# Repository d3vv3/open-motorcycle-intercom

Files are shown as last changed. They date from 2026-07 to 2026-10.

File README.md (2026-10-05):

<p align="center">
    OpenHelmet Logo
    <br/>
    <b>Open Source Mesh and Bluetooth Motorcycle Intercom</b>
    <br/>
    <br/>
    <a href="https://openhelmet.devve.space">website</a> | <a href="https://discord.gg/XxBSnwSDst">discord</a>
</p>

OpenHelmet is an **open-source, motorcycle intercom system**
designed to outperform current proprietary solutions in **latency, scalability, transparency, and hackability**.

## Key goals

- Open protocol and open firmware
- Commodity, off-the-shelf hardware
- Use any microphone and any speakers from your existing helmet setup
- Mesh networking for 4-8+ riders
- Real-time full-duplex voice
- 8-16 hours of active riding per charge
- Bluetooth phone and media audio (calls, GPS, music, etc)
- Interoperability with legacy Bluetooth intercoms (Cardo, Sena, etc.) via standard profiles

This project explicitly avoids reverse-engineering proprietary intercom protocols.
Interoperability is achieved **only through standard Bluetooth audio profiles**.

---

## Why

- Cardo/Sena mesh protocols are proprietary and closed
- True mesh interoperability with and between them is impossible today
- Voice communication requires **deterministic latency**, not best-effort networking

As a result, OpenHelmet is designed around **custom real-time audio transport**.

---

## Roadmap

### Single-MCU

See [the wiring guide](docs/wiring.md) for the ESP32-S31 Function CoreBoard-1.

- [x] **ESP32-S31 Function CoreBoard-1** with 16 MB flash and 16 MB PSRAM
- [x] Onboard ES8311 capture/codec and NS4150B/J9 output
- [x] TDMA mesh protocol over [ESP-NOW](https://www.espressif.com/en/solutions/low-power-solutions/esp-now) (2.4 GHz)
- [x] LC3 low-bitrate voice
- [x] Classic Bluetooth A2DP sink, AVRCP, and HFP HF client
- [x] VOX for voice activation
- [x] Configure ESP32 tx power to 20 dBm (100 mW) for ESP-NOW
- [x] Silence suppression - most silent audio frames are suppressed; control traffic and occasional comfort updates remain
- [x] Receive mixing with first-speaker retention; a new active source can replace the longest-silent source after 400 ms

Limitations:
- ESP-NOW is not interoperable with nRF52 ESB.
- The ESP-NOW and Bluetooth stacks share the same radio, so mesh cannot reach realtime performance when Bluetooth is active.

### Dual-MCU

Development and validation only. Check [the wiring guide](docs/wiring.md) for
the S31/nRF52840 SPI wiring.

The nRF52840 firmware uses the radio's +8 dBm output directly.
An nRF21540 is needed for additional range, efficiency and antenna radio distribution. See "Custom PCB" section below.

> The nRF21540 is needed for actual range improvements.
> The nRF52840 alone is not a range improvement over the ESP32-S31.

- [x] **ESP32-S31 + Nordic nRF52840**
- [x] TDMA mesh protocol over [ESB](https://docs.nordicsemi.com/bundle/ncs-latest/page/nrf/protocols/esb/index.html) radio with custom PHY control
  > ESB is configured for 2 Mbps with +8 dBm TX power (`OMI_ESB_BITRATE` / `OMI_ESB_TX_POWER_DBM`).
- [x] SPI audio & control bridge between MCUs
  > The nRF52840 is the SPI master and polls the ESP32 bridge every 2 ms.
- [x] Noise suppression and echo cancellation paths
- [ ] Allow user to choose between [ESP-NOW](https://www.espressif.com/en/solutions/low-power-solutions/esp-now) and [ESB](https://docs.nordicsemi.com/bundle/ncs-latest/page/nrf/protocols/esb/index.html)
  > ESP-NOW is not interoperable with nRF52 ESB. The firmware currently selects ESB when the bridge is detected and otherwise falls back to ESP-NOW; comparative range, power, and latency remain to be measured.
- [x] Relay grants limited to at most two active speakers
- [x] Three-source receive mixer with first-speaker retention and 400 ms silent-source eviction
- [x] Silence suppression - most silent audio frames are suppressed; control traffic and occasional comfort updates remain
- [x] Bluetooth media playback (music, GPS, etc.) during mesh operation.

### Custom PCB

- [x] Schematic
- [ ] PCB layout
- [x] Include [nRF21540 RF FEM](https://www.nordicsemi.com/Products/nRF21540) in the schematics and PCB design

See the [wiring guide](docs/wiring.md) for the current assembled prototype.

### Ongoing

- [x] Mute mesh during phone call; resume mesh after call ends
- [x] Mesh channels with RGB LED channel indicator by color (e.g. green=1, red=2, blue=3, etc.)
- [x] Buttons for channel selection, volume, mesh toggle, and Bluetooth pairing
- [x] Multi-hop mesh
- [x] Replace beeps with voice prompts for button operations
- [ ] Power budgeting and optimization for 8-16 hours of active riding per charge
- [ ] Testing on real motorcycle rides
- [ ] E2EE

---

## Transport Protocol Design

### Why Not Bluetooth Mesh / BLE Audio

- High latency
- Unpredictable scheduling
- Poor scaling for continuous audio

These technologies are unsuitable for real-time group voice.

---

## Custom Mesh Strategy

### Scheduled Voice and Control

OpenHelmet divides each 20 ms TDMA frame into scheduled voice slots and a control window:

- **TDMA** for mesh audio packets
- A rotating owner for joined-node control traffic; coordinator SYNC frames have a reserved window
- Bounded randomized contention for unjoined ESP-NOW JOIN requests

#### TDMA (Voice)

Each current mesh audio payload represents 20 ms of sound: two 10 ms LC3 frames, encoded as 24 bytes each. These 48 bytes travel together in one packet, not in separate TDMA slots.

On the nRF transport, a bundle can also carry previous audio frames for loss recovery. This increases packet size without changing the 20 ms transmission cadence.

- Fixed time slots per node
- One bounded transmission opportunity per node per 20 ms TDMA frame
- Deadline checks reject work that is already late; they do not guarantee exact RF completion timing

Configured frame structure (20 ms frame, up to 8 nodes; durations include guard time):

```
| Slot 1 | Slot 2 | Slot 3 | ... | Slot 8 | Control | Margin |
|  2 ms  |  2 ms  |  2 ms  | ... |  2 ms  |   2 ms  |  2 ms |
```

- Voice slots: 8 × 2 ms = 16 ms
- Control window: 2 ms (scheduled sync/topology/status traffic)
- Frame margin: 2 ms
- Voice and control deadlines reserve the last 500 µs of each nominal 2 ms window, leaving 1.5 ms before the deadline

VOX suppresses local LC3 encoding and audio transmission during silence, after its hangover period. Capture and voice detection continue. The TDMA schedule remains unchanged, and synchronization, keepalives, and required relay/control traffic continue.

Motorcycle groups are small and topology changes slowly, making TDMA practical.

#### Control

Used for:
- Joining/leaving the group
- Topology updates
- Slot maps and synchronization

Joined-node control packets use a bounded queue and scheduled ownership. Unassigned ESP-NOW JOIN requests use a minimum interval plus randomized jitter. These rules reduce contention, but they do not guarantee collision-free RF operation.

---

## Quick Start

For published paired flash bundles and the alpha/stable release process, see
[Firmware releases](docs/releases.md).

### Prerequisites

- [ESP-IDF v6.1 preview](https://docs.espressif.com/projects/esp-idf/en/release-v6.1/esp32s31/get-started/)
- [ESP32-S31 Function CoreBoard-1](https://docs.espressif.com/projects/esp-idf/en/release-v6.1/esp32s31/get-started/) with 16 MB flash and 16 MB PSRAM
- ESP32-S31 support in ESP-IDF v6.1 is preview
- CI pins a tested ESP-IDF image that includes the upstream S31 Bluetooth
  sniff-subrate fix. The mutable `v6.1` tag does not contain that fix.
- (Optional) XIAO nRF52840
- USB-C data cables
- [Development environment and ESP32 setup](docs/getting_started.md)
- [Audio and dual-MCU wiring guide](docs/wiring.md)
- (Optional) [KiCad](https://www.kicad.org/)

### Build

```bash
# Optional local environment example (path is machine-specific; this installation
# may use the unpatched v6.1 image and does not include the S31 sniff-subrate fix)
source "$HOME/.espressif/tools/activate_idf_v6.1.sh"

# Select the ESP32-S31 preview target
idf.py --preview set-target esp32s31

# Build firmware
idf.py build
```

For the tested SDK image with the tested fix, use the same immutable image as CI
instead of a local v6.1 installation:

```bash
docker run --rm --user "$(id -u):$(id -g)" -e HOME=/tmp \
  -v "$PWD:/project" -w /project \
  espressif/idf@sha256:8ac794c57fd4cac246cb8d2ada4002fa26337ac7df683047b5b83743dbedb6b7 \
  bash -lc 'idf.py --preview set-target esp32s31 && idf.py build'
```

That image reports ESP-IDF commit `9a97f6c54ec638111ce55cd36581b3c192f15207`
and S31 Bluetooth binary commit `3d8cee57c4ccff603d4f52fe16be1f04ece78ede`;
the latter includes the upstream sniff-subrate fix. The stable `espressif/idf:v6.1`
tag does not include this fix. A delayed BOOT guard alone does not fix
phone-originated transitions: cooldown handling and the external Bluetooth
controller fix are also required.

For the optional XIAO nRF52840 firmware, use nRF Connect SDK v3.4.1 and the same board target as CI:

```bash
west build -b xiao_ble/nrf52840 ./nrf_mesh -d ./build-nrf
```

### Recovery and Flashing

```bash
# Find your serial port
ls /dev/ttyACM* /dev/ttyUSB*

# Native USB JTAG/OpenOCD with board/esp32s31-builtin.cfg is the validated
# recovery path on the current setup. Serial flashing has proved unreliable here.
```

### Monitor Serial Output

```bash
# Option 1: Using idf.py (interactive, requires TTY)
idf.py -p /dev/ttyACM0 monitor

# Option 2: Using stty + cat (non-interactive)
stty -F /dev/ttyACM0 115200 raw -echo && cat /dev/ttyACM0
```

**Exit monitor:** `Ctrl+]`

### Expected Boot Log

```
I (xxx) omi: ========================================
I (xxx) omi: OMI - Open Motorcycle Intercom
I (xxx) omi: Phase 2: Single-Hop RF Link
I (xxx) omi: ========================================
I (xxx) omi: Boot time: <milliseconds> ms
I (xxx) omi: IDF version: v6.1
I (xxx) omi: Free heap: <bytes> bytes
I (xxx) omi: ========================================
I (xxx) omi: nRF52840 not detected - using ESP-NOW transport
I (xxx) omi: Mesh networking ready (desired state: disabled)
I (xxx) omi: System running!
```

### Troubleshooting

| Issue | Solution |
|---|---|
| Device not found | Use a data cable (not charge-only), try different USB port |
| Garbage characters in monitor | Wrong baud rate, use 115200 |

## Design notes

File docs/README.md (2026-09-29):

# OpenHelmet Documentation

See the [project README](../README.md) for an overview and project progress.

## Start Here

- [Getting started](getting_started.md): development setup, firmware builds, and initial checks.
- [Wiring](wiring.md): CoreBoard audio, XIAO SPI connections, power arrangements, and flashing preparation.
- [Button controls](buttons.md): three external buttons and voice prompts; BOOT is for ROM download only on new S31 firmware.

## System Design

- [Architecture](architecture.md): component responsibilities and transport selection.
- [Audio pipeline](audio.md): capture, codecs, playback, and Bluetooth audio routes.
- [Mesh protocol](protocol.md): packet formats, mesh control messages, and SPI flow control.
- [Adaptive mesh](mesh.md): topology, relay and handover contracts, limits, and hardware verification plan.
- [TDMA scheduling](tdma.md): voice slots, control windows, and timing constraints.

## Testing and Development

- [Pipeline telemetry](pipeline_telemetry.md): counters and tools for tracing audio delivery and drops.
- [CPU profiling](s31-cpu-profiling.md): optional task profiling, timing measurements, and interpretation limits.

## Investigation History

- [S31 Bluetooth / ESP-NOW coexistence](s31-bluetooth-coexistence.md): September 2026 experiments using the S31's shared radio.
  This report predates the separate nRF ESB setup and does not describe its performance.

The documentation is being updated for LC3, protocol v5, and NCS 3.4.1.
Some linked guides still describe earlier versions; dated reports retain their original test context.

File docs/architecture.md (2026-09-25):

# Architecture Overview

OpenHelmet uses an ESP32-S31 Function CoreBoard-1 for audio and phone connectivity.
An optional XIAO nRF52840 Sense provides a separate mesh radio.

## System Map

```mermaid
flowchart LR
    Phone[Phone] <-->|Bluetooth| S31[ESP32-S31]
    Mic[Onboard microphone] --> S31
    S31 --> Speaker[Speaker]
    S31 <-->|SPI: encoded LC3 audio and control| NRF[nRF52840]
    NRF <-->|ESB| Peers[Other mesh nodes]
```

The diagram shows the separate-radio setup. The nRF forwards encoded audio; it does not run the audio codec.

| Responsibility | Owner |
|---|---|
| Microphone capture, VOX, LC3 encoding and decoding | S31 |
| Playback, music mixing, and notification sounds | S31 |
| Bluetooth music, media controls, and phone-call routes | S31 |
| Buttons and application policy | S31 |
| ESB radio, mesh membership, TDMA, and relaying | nRF, when selected |
| SPI transfers | nRF master, S31 slave |

Mesh audio is 16 kHz mono. Each 20 ms audio payload contains two 10 ms LC3 frames.
VOX silence stops local encoding and audio transmission, while capture and mesh control traffic continue.

## Transport Selection

At startup, the S31 probes for a compatible LC3 nRF bridge.

- **nRF ESB:** The nRF owns mesh communication. S31 Wi-Fi and ESP-NOW are disabled; Bluetooth remains enabled.
- **ESP-NOW fallback:** Without a compatible bridge, the S31 also owns the mesh radio and TDMA schedule.

Mesh voice, Bluetooth music, and notifications can mix locally. Phone calls take priority over those playback sources.

Bluetooth music and two-way mesh voice have worked together on two nRF-equipped pairs.
Larger groups and sustained call performance still need validation.

## Details

- [Wiring and power](wiring.md)
- [Audio pipeline](audio.md)
- [Packet formats and SPI flow control](protocol.md)
- [TDMA scheduling](tdma.md)
- [Button gestures](buttons.md)

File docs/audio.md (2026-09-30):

# Audio Pipeline

This page describes the tested ESP32-S31 LC3 mesh configuration. The S31 handles all audio processing;
the nRF52840 transports encoded audio over ESB.

## Formats and Signal Path

| Domain | Format | Samples per 20 ms |
|---|---|---:|
| Hardware capture and playback | 48 kHz, mono, signed 16-bit PCM | 960 |
| Mesh voice | 16 kHz, mono, signed 16-bit PCM | 320 |
| Encoded mesh audio | Two 10 ms LC3 frames, 24 bytes each | 48 bytes total |

The LC3 payload rate is 19.2 kbit/s, excluding headers and redundancy.

```text
Microphone -> 48-to-16 kHz conversion -> voice cleanup -> VOX -> LC3 -> mesh
Mesh -> packet recovery -> LC3 decode -> voice mix -> 16-to-48 kHz conversion -> speaker
Bluetooth music -> stereo downmix and rate conversion -> speaker mix
```

The onboard ES8311 codec and NS4150B amplifier handle physical audio I/O.
See [wiring](wiring.md) for the speaker connection and pin details.

## Codec Ownership and Memory

The tested build enables `ESP_LC3_BENCH`, `S31_LC3_WIRE`, `S31_LC3_SERIALIZE`, and `S31_LC3_SINGLE_OWNER`.
These CMake options default to OFF; the benchmark and serialization options are prerequisites for this path.
Capture, playout, and the dedicated LC3 owner task run on core 1.
All vendor LC3 operations run through the owner task, including resets. Preserve this arrangement when changing task placement.

Mesh mode uses LC3; local codec loopback still uses Opus.
The nRF does not encode, decode, or mix audio.

Audio initialization requires the CoreBoard's expected 16 MB PSRAM.
Route buffers and Speex resampler state and scratch buffers use PSRAM in the S31 configuration.
Speex uses fixed-point quality-3 resampling, with a full sinc table to reduce conversion work.

## VOX and Silence

VOX measures microphone RMS once per 20 ms frame. Current defaults are:

- Activation threshold: `0.03` of full scale; deactivation threshold: `0.010`.
- Minimum active time: 500 ms; hangover: 500 ms.
- Forced continuous transmission: disabled.

During VOX silence, the LC3 mesh path skips encoding and local audio transmission.
Microphone capture, voice detection, Bluetooth microphone routing, and mesh control traffic continue.
Local silence does not stop reception of other speakers.

There is no pre-roll buffer. Quiet speech before activation can lose its opening milliseconds;
that behavior is currently accepted. RMS detection can also respond to noise or music.

See [protocol.md](protocol.md#lc3-audio-bundles) for quiet-slot sequencing and predecessor handling.

## Receive and Playback

Up to three remote sources have independent packet, decoder, and resampler state.
Predecessor frames can recover missing audio; remaining gaps use concealment before an empty stream becomes idle.
These decoder slots are separate from the mesh's two active-speaker relay grants.

Packet and PCM buffers provide startup prefill and absorb timing variation.
Their presence means codec frame duration alone does not describe end-to-end latency.

Outside phone calls, remote voice, Bluetooth music, and notification tones can mix locally.
An answered or held HFP call gates local mesh mic TX and local mesh playback immediately;
the mesh stays joined and continues control traffic and relaying other participants' audio.
Ringing and outgoing dialing/alerting alone do not gate mesh audio.
An incoming announcement is urgent and canceled on answer, reject, or disconnect;
a completed answered call gets one end beep.
On call end the local gate remains closed until transport audio is flushed,
the mesh RX decoder is reset, and the transport confirms resume.
Audio already submitted to RF or I2S hardware before the call edge cannot be retracted.

## Bluetooth and Voice Cleanup

- **A2DP:** The S31 decodes SBC music, downmixes stereo, and resamples to the 48 kHz speaker domain.
  Hardware playback tests used 44.1 kHz stereo input.
- **AVRCP:** Provides media controls and metadata.
- **HFP:** Hands-Free call audio uses CVSD or mSBC, with 8/16 kHz microphone and playback routes.

Microphone processing includes a high-pass filter and mic-only noise cleanup.
ESP-SR acoustic echo cancellation is disabled. Noise cleanup is not acoustic echo cancellation.
The disabled AEC path also skips unnecessary playback-reference conversion.

See [button gestures](buttons.md) for media, call, mesh, and pairing controls.

## Validation and Diagnostics

Bluetooth music and two-way LC3 mesh voice have worked together on two nRF-equipped pairs.
Quiet-state tests confirmed continued capture with zero LC3 encoding or audio handoff.
Larger groups, sustained calls, and broader acoustic conditions still need testing.

Codec initialization includes a reset sequence that restored speaker output after MCU-only resets.
`AUDIO_OUT` diagnostics report submitted PCM levels, write results, and codec/amplifier register state.
Successful writes and nonzero samples do not prove audible output.

See [pipeline telemetry](pipeline_telemetry.md) for delivery and dropout counters,
or [architecture](architecture.md) for the system overview.

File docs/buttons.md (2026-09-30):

# Buttons

Use the **-**, **play**, and **+** buttons. For setup, see [button wiring](wiring.md#external-buttons).
Hold for the time shown, then release to perform the action.

| Action | Controls |
| --- | --- |
| Mesh volume (Bluetooth call volume during an active or held call) | Tap **- / +** |
| Bluetooth volume (music and calls) | Hold **play** and tap **- / +** |
| Play or pause music | Tap **play** |
| Answer or end a call | Tap **play** |
| Previous or next song | While Bluetooth music is playing, hold **- / +** for **1 second** |
| Previous or next mesh channel | Pause Bluetooth music, then hold **- / +** for **1 second** |
| Turn mesh on or off | Hold **play** for **2-5 seconds** |
| Pair a phone | Hold **play** for **6 seconds**, then connect within **2 minutes** |

- Three beeps mean minimum or maximum volume. Volume levels reset when you restart the device.
- Channels cycle **green -> red -> blue**. The LED shows your channel, which is saved across restarts.
- Use the same channel as the people you want to talk to.
- After adjusting Bluetooth volume, releasing **play** does not trigger another action.
- Bluetooth volume also adjusts the paired phone's volume when supported; music and calls keep separate levels, and call volume moves in coarser steps.
- Incoming calls announce once; ringing does not mute the mesh. Answering or holding a call mutes only this device's mesh microphone and local mesh playback. Other mesh participants remain connected and can relay through this device. Ending the call restores local mesh audio after the transport confirms the flush.

The onboard **BOOT** button is for firmware flashing, not everyday controls.

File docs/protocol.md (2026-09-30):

# Mesh v5 and Bridge v6

The current LC3 firmware uses on-air mesh version `0x05` and SPI bridge version `6`.
The name `AUDIO_V2` identifies a packet format; it does not mean protocol version 2.
For routing, topology, membership, speaker grants, and handover behavior, see [adaptive mesh](mesh.md).

## Mesh Radio Header

Every mesh packet starts with this packed 9-byte header:

| Offset | Field | Bytes | Meaning |
|---:|---|---:|---|
| 0 | `version` | 1 | `0x05` |
| 1 | `type` | 1 | Message ID below |
| 2 | `src_id` | 1 | Source node; `0` for an unassigned joining node |
| 3 | `seq` | 1 | Radio packet sequence |
| 4 | `ttl` | 1 | Remaining hop limit |
| 5 | `flags` | 1 | Relay request, relayed, and speaker-granted bits |
| 6 | `talk_channel` | 1 | Logical talk group (1-3); mismatched groups are rejected |
| 7 | `payload_len` | 2 | Payload length, little-endian |

Assigned node IDs are 1-8; the authoritative slot map assigns their TDMA slots (holes need not be renumbered).
Receivers reject mismatched protocol versions and invalid packet lengths.

| ID | Message | Purpose |
|---:|---|---|
| `0x01` | `AUDIO` | ESP-NOW audio; rejected by the current nRF audio path |
| `0x02` / `0x03` | `JOIN` / `JOIN_ACK` | Legacy membership IDs |
| `0x04` | `LEAVE` | Departure |
| `0x05` / `0x06` | `SYNC` / `SLOT_MAP` | Legacy timing / slot-map ID |
| `0x07` / `0x08` | `STATUS` / `KEEPALIVE` | Node status and liveness |
| `0x09` / `0x0A` | `SPEAKER_GRANT` / `SPEAKER_RELEASE` | Speaker-control IDs |
| `0x0B` / `0x0C` | `JOIN_V2` / `JOIN_ACK_V2` | Legacy identity-bearing membership IDs |
| `0x0D` | `AUDIO_V2` | LC3 bundle used by nRF ESB |
| `0x0E` | `TOPOLOGY` | Direct observations, 32-bit report sequence (47-byte payload) |
| `0x0F` / `0x10` | `JOIN_V3` / `JOIN_ACK_V3` | Identity-bearing targeted JOIN/ACK (15 bytes each) |
| `0x11` | `SYNC_V3` | Term, leader identity, joined member count, frame/phase and relay depth (20 bytes) |
| `0x12`-`0x15` | `HANDOVER_PREPARE` / `ACK` / `COMMIT` / `CANCEL` | Planned handover (25-byte proposal or 11-byte ACK) |
| `0x16` | `MEMBERSHIP_V3` | Full authoritative ID/identity/slot map with term and revision (79 bytes) |
| `0x17` | `SPEAKER_REQUEST` | Pre-grant voice activity/release, 13 bytes; one forwarding hop |

These are shared IDs; not every transport uses every message.
The nRF coordinator requires the LC3 capability bit in `JOIN_V3` requests.
ESP-NOW membership does not enforce the same capability check; use matching firmware on all nodes.

## LC3 Audio Bundles

Mesh voice is 16 kHz mono. Each 20 ms audio unit contains two 10 ms LC3 frames, 24 bytes each.
The nRF forwards these encoded bytes; the S31 performs encoding and decoding.

An `AUDIO_V2` payload begins with an 8-byte header:

```text
codec | frame_ms | stream_id | flags | current_seq (2 bytes) | current_len | previous1_len
```

All fields are one byte except `current_seq`, which is **big-endian**.
The codec is `0x02` (LC3), duration is `20`, and every present audio unit must contain exactly 48 bytes.
`stream_id` identifies the source, not a new speech segment. The S31 accepts zero or the matching source node ID.

Audio data follows in this order: oldest predecessor, immediate predecessor, current audio.
The oldest predecessor's length is inferred from the remaining payload size.

| Flag | Meaning |
|---:|---|
| `0x01` | Current audio active |
| `0x02` / `0x04` | Immediate predecessor present / active |
| `0x08` / `0x10` | Oldest predecessor present / active |
| `0x20` | Relayed bundle indicator |

Other flag bits are rejected. The S31 currently attaches at most one predecessor; the format supports two.

| Audio units | Bundle bytes | Bytes with mesh header |
|---|---:|---:|
| Current only | 56 | 65 |
| Current + one predecessor | 104 | 113 |
| Current + two predecessors | 152 | 161 |

The 16-bit audio sequence is separate from the 8-bit radio packet sequence.
During VOX silence, no LC3 audio is encoded or sent. There is no explicit end-of-speech packet.
The sender clears cached predecessors and advances through at most five quiet sequence slots before holding the sequence.
The receiver uses bounded concealment before treating an empty stream as idle.

ESP-NOW uses its separate `AUDIO` payload format. The S31 LC3 build requires LC3 there too; it does not negotiate codecs.

## Control and Delivery

Coordinator SYNC is scheduled every 200 ms. The nRF queues STATUS and KEEPALIVE every second;
ESP-NOW schedules keepalives every 500 ms. Peer timeout is 3 seconds.
These control messages continue during VOX silence.

The coordinator grants relay service to at most two active speakers. `SPEAKER_REQUEST` can travel through one relay before a grant; voice onset may require several control windows before relayed audio is permitted.
Audio starts with TTL 2; the implemented relay path permits one forwarding hop.
See [TDMA scheduling](tdma.md) for slot ownership and deadlines, and [adaptive mesh](mesh.md) for handover, capacity, and latency caveats.

nRF ESB sends with RF acknowledgments disabled. Lost audio is handled through predecessors and receiver concealment, not RF retransmission.
ESP-NOW completion callbacks have separate MAC-layer semantics; they do not prove application delivery.

## S31/nRF SPI Bridge

The nRF is SPI master; the S31 is slave. Transfers are 256 bytes, mode 0, at 4 MHz.
The polling loop has a nominal 2 ms interval, not a guaranteed transaction deadline.
See [wiring](wiring.md) for connections. The `uart_bridge` name is historical; this link uses SPI.

```text
0xAA | LEN | SEQ | TYPE | PAYLOAD... | CRC8 | zero padding...
```

`LEN = payload_length + 2`. CRC8 covers `LEN` through the payload, using polynomial `0x07` and initial value zero.
The 256-byte transfer allows at most 251 payload bytes. SPI sequence numbers are separate from radio and audio sequences.

| ID | Message | Direction |
|---:|---|---|
| `0x01` | Legacy `AUDIO` | Rejected by current nRF firmware |
| `0x02` | `STATUS` | nRF to S31 |
| `0x03` | `MESH_EVENT` | nRF to S31 |
| `0x04` | `CONTROL` | S31 to nRF |
| `0x05` | `LOG` | nRF to S31 |
| `0x06` | `AUDIO_V2` | Both directions |

S31-to-nRF audio carries the bundle directly. nRF-to-S31 audio prefixes the bundle with one source-ID byte.
Receive timestamps are assigned locally; they are not included in this payload.

### Status and Compatibility

The v6 STATUS payload is 10 bytes, in this order:

```text
role | peer_count | node_id | version | mesh_state | slot_index |
coordinator_id | marker | audio_codec | audio_frame_ms
```

Each field is one byte; `slot_index` is signed. The marker is `0xA5`.
Startup selects nRF only after a fresh status advertises version 6, LC3, and 20 ms audio.
Audio transfer additionally requires an ACTIVE mesh and an assigned node ID.
Older 3-byte and 8-byte statuses remain readable but do not establish LC3 compatibility.

### Two Different Acknowledgments

- **Audio admission:** The nRF pulses GPIO ACK for 20 µs after admitting audio to bounded RAM ingress or recognizing its admitted duplicate.
  The S31 retains and repeats unacknowledged SPI audio until ACK or a 50 ms timeout. ACK does not confirm RF delivery.
- **Commands:** MESH_START (`0x01`), MESH_STOP (`0x02`), AUDIO_PAUSE (`0x04`), and AUDIO_RESUME (`0x05`) carry a three-byte payload: command, generation, talk group (all except START ignore the group). PAUSE and RESUME affect only this node's mesh audio origin and local playback; membership, control and third-party relay continue. PAUSE purges local audio at the nRF, while RESUME requires a fresh local flush first.
  A COMMAND_ACK event returns the command, matching generation, and signed result: zero for success, minus one for failure.

### SPI Flow Control

- Both bridge directions send pending control before audio.
- S31 queued outbound audio expires after 120 ms; transfer requires fresh status reporting an ACTIVE mesh and assigned node ID.
- nRF outbound SPI audio drops the oldest entry when full; it has no age expiry.

The nRF owns ESB, mesh membership, TDMA, relay, and synchronization. The S31
owns codec/audio, phone routes, application policy, and SPI slave state.

## Security

CRC detects accidental corruption; it does not authenticate the sender.
On-air authentication, encryption, key management, and secure firmware update are not implemented.

## Source Definitions

- [Mesh header and message IDs](../shared/mesh_protocol_defs.h)
- [LC3 bundle encoder and parser](../shared/audio_bundle.c)
- [Bridge messages and status layout](../shared/bridge_protocol_defs.h)
- [SPI framing and CRC](../shared/bridge_frame.c)

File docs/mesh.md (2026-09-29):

# Mesh

Mesh lets nearby OMI devices talk to each other without a phone or internet connection.

## Get started

1. Hold the center **play** button for **2-5 seconds**, then release to turn mesh on.
2. Choose the same color channel on every device in your group. Green is the default.
3. Speak normally. Voice activation sends speech automatically; there is no push-to-talk button.

Tap **- / +** to adjust mesh volume. See [Buttons](buttons.md) for all controls, including how to turn mesh off.

## Channels

| Channel | Indicator |
| --- | --- |
| Green (default) | Green LED |
| Red | Red LED |
| Blue | Blue LED |

The LED shows the selected channel, which is saved across restarts.
To change channels, **pause Bluetooth music**, then hold **- / +** for **1 second** and release.
While Bluetooth music is playing, the same holds skip songs instead.

## How it works

One device automatically coordinates the group; you do not need to pick it.
The firmware can rearrange the group as links change.

A device between two others can relay their voices: A to B to C is the limit of **two radio hops**, with one relay, not an unlimited chain.
Relaying adds delay. Separate incoming voices play independently rather than waiting for each other.

The design supports up to **eight devices** and **two simultaneous talkers**.
The start of speech may be clipped, and connection changes may interrupt audio.

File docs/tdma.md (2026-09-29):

# TDMA Scheduling

The implemented mesh schedule is shared by ESP-NOW and nRF ESB.

| Item | Value |
|---|---:|
| Maximum nodes | 8 |
| Frame | 20 ms |
| Voice slots | 8 x 2 ms |
| Guard within each voice/control window | 500 µs |
| Control window | 2 ms, from 16 to 18 ms |
| Frame margin | 2 ms, from 18 to 20 ms |
| SYNC | Every 10 frames, about 200 ms |

Each 20 ms audio payload contains two 10 ms LC3 frames: 24 bytes each, 48 bytes total.
They travel together in one packet.
Redundant previous audio increases packet size, not the transmission cadence.

The authoritative slot map assigns each member's slot;
removing a node may leave a hole without renumbering other members,
including through a planned coordinator handover.
ESP-NOW sends at most one local or relay audio packet per node per frame,
alternating under contention.
nRF ESB may attempt a second packet only if guarded remaining airtime suffices;
full-rate local plus relay is not guaranteed.
Relay grants are limited to two active speakers.

The guard leaves 1.5 ms before each slot's deadline.
Deadline checks reject late work but cannot guarantee RF completion timing.

During VOX silence, local LC3 encoding and audio transmission stop after the hangover period.
Capture and voice detection continue. Slots may remain unused, but synchronization, keepalives, and required relay/control traffic continue.

ESP-NOW discovery uses bounded randomized contention.
ESB discovery uses bounded join retries and scan backoff.
These are discovery exceptions, not a general CSMA voice mode.
The schedule does not guarantee collision-free RF operation.

The nRF owns ESB timing when the bridge is active.
Participants synchronize to the coordinator and reacquire SYNC after loss.
Control-window ownership rotates by slot over eight frames (160 ms);
forwarded SYNC uses the relay's current synchronized frame/phase at TX, not its receive timestamp.
A planned successor also sends SYNC in its own control windows after promotion.
S31 GPIO47 provides a physical 48 kHz WS reference, separate from the 16 kHz mono LC3 audio.
The current runtime does not enable WS-based TDMA clock correction.

Earlier two-board operation has been tested; the new adaptive relay/handover paths still await hardware validation, as does eight-node operation.
Timing counters alone do not prove end-to-end audio latency or RF delivery.

See [protocol.md](protocol.md) for packet and bridge formats and [adaptive mesh](mesh.md) for grant acquisition and latency limits.

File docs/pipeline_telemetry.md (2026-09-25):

# Audio Pipeline Telemetry

Firmware emits `PIPE` records through ESP-IDF and Zephyr logs. These examples omit other fields:

```text
PIPE v=1 dev=esp stage=audio part=tx epoch_id=0x1234 uptime_ms=20000 capture_ok=1000 encode_ok=100 vox_skip=900 tx_handoff=100
PIPE v=1 dev=esp stage=espnow part=tx epoch_id=0x5678 uptime_ms=20000 node_mac=aa:bb:cc:dd:ee:ff tx_offer=100 tx_queue_full=2
PIPE v=1 dev=esp stage=transport node=2 source=100 spi_ok=98
PIPE v=1 dev=nrf stage=mesh node=2 ingress_ok=98 rf_tx_ok=96
```

The parser requires `v=1`, `dev`, and `stage`. Most event counts are cumulative.
Queue depths, maxima, current settings, and identity fields are not event counts.

## Stages

| Device | Stage | Boundary |
|---|---|---|
| S31 | `audio` | Separate `tx`, `rx`, `playout`, and `bt` parts for capture, codecs, queues, and playback |
| S31 | `audio_timing` | Music and notification processing time |
| S31 | `transport` | nRF audio handoff, SPI admission, redundancy, and playback queue |
| S31 | `spi` | SPI queue, framing, parser, and ACK handling |
| S31 | `espnow` | Separate `tx` and `rx` parts for ESP-NOW admission, completion, and receive handling |
| S31 | `espnow_timing` | Slot timing, queue age, radio completion, send errors, and internal heap |
| nRF | `spi` | SPI ingress and nRF-to-S31 transactions |
| nRF | `mesh` | Ingress, TDMA, ESB audio, relay, and SPI egress |
| nRF | `tdma` | Due work, coalescing, and late execution |
| nRF | `rf` | ESB completion, timeout, FIFO, and RX restart |

The capture boundary is PCM read from the audio codec, not a direct ADC measurement.
The tested mesh configuration uses LC3; local codec loopback still uses Opus.
Only inspect stages relevant to the selected transport.

## Useful Counters

- **Capture and encoding:** `capture_ok`, `encode_ok`, and `tx_handoff` track successive audio boundaries.
- **VOX silence:** `vox_skip` counts intentionally suppressed LC3 frames, not failures.
  Capture can continue at 50 frames/s while encoding and audio transmission stay at zero.
- **Local discards:** Examples include `tx_queue_full`, `jitter_late`, and `rx_store_reject`.
  Some counters overlap; do not add every drop or gap counter into one loss total.
- **Reception and playback:** `rx_store_pop`, `decode_ok`, `conceal`, and `play_ok` distinguish received audio from concealment and output writes.
- **Radio completion:** nRF `rf_tx_ok` and ESP-NOW `tx_radio_ok` describe local completion, not remote application delivery.

Control traffic and required relaying can continue while the local microphone is silent.
Retries and duplicate rejection also need separate interpretation from lost audio.

## Compare Intervals Carefully

Use changes between samples, not lifetime totals, to assess a test window.

- Audio records carry `epoch_id`, `uptime_ms`, and `part`; they do not carry a MAC address. Keep serial-port identity attached.
- ESP-NOW records also carry `node_mac`. Keep different stages, parts, and epochs separate.
- S31 nRF-transport and nRF records lack those epoch and uptime fields. Use capture timestamps and boot boundaries.
  Node IDs alone are not stable device identities.

Derived ESP rates require at least two samples with increasing uptime in one epoch.
Each counter must cover the full interval without decreasing. Missing or reset counters are unavailable, not zero.
Generic counter summaries handle decreases as resets, but cannot establish continuity across an unobserved reboot.

Sender and receiver windows must refer to the same traffic and time period.
Aggregate counters alone do not establish an exact end-to-end delivery percentage.

## Capture and Reports

From the repository root, substitute your serial ports in this example:

```sh
uv run benchmark.py --duration 120 --baud 115200 \
  --ports /dev/ttyACM0 /dev/ttyACM1 --out-dir logs/benchmark
```

Prefer stable `/dev/serial/by-id/` paths when available. Each run writes `raw/`, `summary.json`, and `report.txt`.

The report adds `WARN` for measured ESP discard increases and marks missing interval coverage as unavailable.
Missing ESP coverage can change otherwise-OK health to `UNKNOWN`; existing warnings or failures remain.
Health is a diagnostic summary, not proof of clean audio or successful radio delivery.

Optional `cpu` records report task runtime; `cpu_span` records measure elapsed wall time, including waits and preemption.
See [CPU profiling](s31-cpu-profiling.md) for interpretation and overhead.

Counters and successful I2S writes do not prove audible output, acoustic latency, coexistence quality, or battery life.
See [audio.md](audio.md) for the pipeline and its limits.

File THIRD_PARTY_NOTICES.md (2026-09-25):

# Third-Party Notices

## Espressif ESP-SR 2.5.4

ESPRESSIF MIT License

Copyright (c) 2018 <ESPRESSIF SYSTEMS (SHANGHAI) PTE LTD>

Permission is hereby granted for use on all ESPRESSIF SYSTEMS products, in which case,
it is free of charge, to any person obtaining a copy of this software and associated
documentation files (the "Software"), to deal in the Software without restriction, including
without limitation the rights to use, copy, modify, merge, publish, distribute, sublicense,
and/or sell copies of the Software, and to permit persons to whom the Software is furnished
to do so, subject to the following conditions:

The above copyright notice and this permission notice shall be included in all copies or
substantial portions of the Software.

THE SOFTWARE IS PROVIDED "AS IS", WITHOUT WARRANTY OF ANY KIND, EXPRESS OR
IMPLIED, INCLUDING BUT NOT LIMITED TO THE WARRANTIES OF MERCHANTABILITY, FITNESS
FOR A PARTICULAR PURPOSE AND NONINFRINGEMENT. IN NO EVENT SHALL THE AUTHORS OR
COPYRIGHT HOLDERS BE LIABLE FOR ANY CLAIM, DAMAGES OR OTHER LIABILITY, WHETHER
IN AN ACTION OF CONTRACT, TORT OR OTHERWISE, ARISING FROM, OUT OF OR IN
CONNECTION WITH THE SOFTWARE OR THE USE OR OTHER DEALINGS IN THE SOFTWARE.

The public `esp_aec.h` header is Apache-2.0 licensed; retain its upstream
Apache-2.0 notice when redistributing that header.

## Espressif ESP Codec Device 2.0.0-beta5

Espressif Modified MIT License

Copyright (c) 2023-2026 Espressif Systems (Shanghai) CO., LTD

Permission is hereby granted for use EXCLUSIVELY with Espressif Systems products.
This includes the right to use, copy, modify, merge, publish, distribute, and sublicense
the Software, subject to the following conditions:

1. This Software MUST BE USED IN CONJUNCTION WITH ESPRESSIF SYSTEMS PRODUCTS.
2. The above copyright notice and this permission notice shall be included in all copies
   or substantial portions of the Software.
3. Redistribution of the Software in source or binary form FOR USE WITH NON-ESPRESSIF PRODUCTS
   is strictly prohibited.

THE SOFTWARE IS PROVIDED "AS IS", WITHOUT WARRANTY OF ANY KIND, EXPRESS OR IMPLIED,
INCLUDING BUT NOT LIMITED TO THE WARRANTIES OF MERCHANTABILITY, FITNESS FOR A PARTICULAR
PURPOSE AND NONINFRINGEMENT. IN NO EVENT SHALL THE AUTHORS OR COPYRIGHT HOLDERS BE LIABLE
FOR ANY CLAIM, DAMAGES, OR OTHER LIABILITY, WHETHER IN AN ACTION OF CONTRACT, TORT OR
OTHERWISE, ARISING FROM, OUT OF OR IN CONNECTION WITH THE SOFTWARE OR THE USE OR OTHER
DEALINGS IN THE SOFTWARE.

SPDX-License-Identifier: LicenseRef-Espressif-Modified-MIT

## SpeexDSP Resampler 1.2.1

Vendored from `xiph/speexdsp` commit
`1b28a0f61bc31162979e1f26f3981fc3637095c8` (release `SpeexDSP-1.2.1`).
The source archive SHA-256 is
`59a53188f6d6ca2b48752f533523986a0604d2526eb50789b8fb09aa6b12645f`.

Copyright 2002-2008 Xiph.org Foundation
Copyright 2002-2008 Jean-Marc Valin
Copyright 2005-2007 Analog Devices Inc.
Copyright 2005-2008 Commonwealth Scientific and Industrial Research Organisation (CSIRO)
Copyright 1993, 2002, 2006 David Rowe
Copyright 2003 EpicGames
Copyright 1992-1994 Jutta Degener, Carsten Bormann

Redistribution and use in source and binary forms, with or without
modification, are permitted provided that the following conditions
are met:

- Redistributions of source code must retain the above copyright
  notice, this list of conditions and the following disclaimer.

- Redistributions in binary form must reproduce the above copyright
  notice, this list of conditions and the following disclaimer in the
  documentation and/or other materials provided with the distribution.

- Neither the name of the Xiph.org Foundation nor the names of its
  contributors may be used to endorse or promote products derived from
  this software without specific prior written permission.

THIS SOFTWARE IS PROVIDED BY THE COPYRIGHT HOLDERS AND CONTRIBUTORS
``AS IS'' AND ANY EXPRESS OR IMPLIED WARRANTIES, INCLUDING, BUT NOT
LIMITED TO, THE IMPLIED WARRANTIES OF MERCHANTABILITY AND FITNESS FOR
A PARTICULAR PURPOSE ARE DISCLAIMED. IN NO EVENT SHALL THE FOUNDATION OR
CONTRIBUTORS BE LIABLE FOR ANY DIRECT, INDIRECT, INCIDENTAL, SPECIAL,
EXEMPLARY, OR CONSEQUENTIAL DAMAGES (INCLUDING, BUT NOT LIMITED TO,
PROCUREMENT OF SUBSTITUTE GOODS OR SERVICES; LOSS OF USE, DATA, OR
PROFITS; OR BUSINESS INTERRUPTION) HOWEVER CAUSED AND ON ANY THEORY OF
LIABILITY, WHETHER IN CONTRACT, STRICT LIABILITY, OR TORT (INCLUDING
NEGLIGENCE OR OTHERWISE) ARISING IN ANY WAY OUT OF THE USE OF THIS
SOFTWARE, EVEN IF ADVISED OF THE POSSIBILITY OF SUCH DAMAGE.

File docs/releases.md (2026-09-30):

# Firmware Releases

## Channels and Versions

`next` is the intended default development branch and publishes alpha releases
after successful push verification. The semantic-release configuration uses
`{ "name": "next", "prerelease": "alpha" }`; tags are `v${version}`.
Changing the GitHub default branch is a separate administrator action, not done
by this configuration.

`main` is the stable branch. Pushes to `main` run verification only, never release.
When ready, merge `next` into `main`, then manually run the **Build** workflow
with **Run workflow** on `main`. With the historical `v0.1.0` baseline and the
current feature history, the first stable release is expected to be `v0.2.0`.
Manual dispatch on `next` can also publish an alpha. Pull requests and all other
branches cannot publish. A manual run still needs a releasable commit; it does
not force a new version.

Conventional Commits determine versions relative to the last reachable release:

| Commit | Release increment |
| --- | --- |
| `fix: ...`, `perf: ...` | Patch |
| `feat: ...` | Minor |
| `feat!: ...`, any type with `!`, or a `BREAKING CHANGE:` footer | Major |
| `docs: ...`, `test: ...`, `chore: ...` without breaking changes | None |

Both analysis and release notes explicitly use the `conventionalcommits` preset.
Normal SemVer rules apply before 1.0 too: a breaking change from 0.x produces
1.0.0 (or 1.0.0-alpha.1 on `next`), not a special 0.x minor bump. Alpha sequence
numbers are managed automatically. Preserve Conventional Commit messages when
merging or squash-merging.

## Initial Bootstrap

The historical ESP32-S3 release is `v0.1.0`, pointing to
`9b3376b11009f66f74fd34a01f65635a117dd591`. Establish that tag on this exact
ancestor before enabling publication. Do not tag the current S31 source as
`v0.1.0`: the ancestor baseline makes the existing `feat:` commits select
`v0.2.0-alpha.1` for the first generated ESP32-S31 release on `next`.
Confirm this with a semantic-release dry run before publishing; newer breaking
commits can change the expected version. Bootstrap tags and publication require
explicit maintainer action; installing this tooling creates neither.

The historical bundle can be built independently, without tagging or publishing:

```sh
python3 tools/release/build.py --version 0.1.0 \
  --source-sha 9b3376b11009f66f74fd34a01f65635a117dd591 \
  --profile esp32s3 --esp-image 'espressif/idf@sha256:REPLACE_WITH_VERIFIED_IDF_5_5_2_DIGEST' \
  --output-dir dist/legacy
```

Resolve and verify the historical ESP-IDF 5.5.2 image digest first; the placeholder
is intentionally invalid. The builder obtains the historical pinned NCS image
from that commit. This is an experimental S3/nRF pair: ESP32-S3 has **no native
Classic Bluetooth** and the pair is **not compatible with S31 LC3 firmware**.
Do not mix its nRF firmware with an S31 release.

## Published Bundles

Each release contains five required assets (the current builder names the UF2
`nrf52840`, not `xiao-nrf52840`):

- `omi-VERSION-esp32s31.zip`: ESP application, bootloader, partition table,
  generated flash metadata and matching flashing instructions.
- `omi-VERSION-nrf52840.uf2`: paired XIAO nRF52840 application firmware.
- `omi-VERSION-debug.zip`: ELF files and dependency/build provenance.
- `manifest.json`: firmware version, full source commit, protocol versions,
  pinned builder images, validation metadata and asset hashes/sizes.
- `SHA256SUMS`: checksums for the other four files, including the manifest.

Download both MCU images from the same release and verify `SHA256SUMS` before
flashing. Follow the ESP archive's generated README: flash offsets come from
the build's `flasher_args.json`, not hard-coded guesses. S31 instructions include
native USB JTAG/OpenOCD. Copy the UF2 to the XIAO bootloader drive; do not erase
or replace the nRF bootloader. The debug archive is not a flash bundle.

Firmware SemVer is separate from the mesh and SPI bridge protocol versions.
An alpha suffix does not establish wire compatibility; check the manifest and
use the paired images. The debug archive captures the resolved ESP component
lock, SDK configuration, frozen West manifest, resolved revisions, IDF commit
and version, and CMake metadata. Pinned containers and archived source provide
traceability, not a claim that rebuilding historical firmware is bit-identical.

## Publication Lifecycle

The release job requires the ESP-IDF, Python/shared-C and nRF verification jobs,
including the existing host sanitizer gates. Ordinary S31 CI builds remain
normal verification builds. Release `prepare` instead invokes the Docker-based
builder with the LC3 release profile against an archive of the exact source SHA:

```sh
python3 tools/release/build.py --version VERSION --source-sha FULL_COMMIT_SHA \
  --profile esp32s31 --output-dir dist/release
```

The output directory must be absent or empty. The builder requires and validates
all five assets, flash inputs, firmware identity, UF2 bounds, and protocol
metadata before returning. Preparation runs **before** semantic-release creates
the tag; validation failure therefore prevents tagging/publication. The GitHub
plugin uploads `dist/release/*`. A later network/upload failure can still leave
a tag or a partial GitHub release; inspect and repair it deliberately rather
than blindly rerunning or moving a published tag.

Release jobs share the `firmware-release` concurrency group, without cancelling
an in-progress publisher. Checkout uses the event's exact `github.sha` with full
history and tags. Remote branch-tip checks reject stale queued runs before
semantic-release and again after preparation; semantic-release also performs
its own branch/push checks. Do not advance a publishing branch during a release:
there is still a small race between the final check and remote tag creation.

Only the release job receives `contents: write`. It uses the built-in
`GITHUB_TOKEN`; issue/PR success and failure comments, labels, and discussions
are disabled, so no issue/PR write permissions are needed. This token does not
trigger downstream tag/release workflows. Building and asset publication are
therefore in this same workflow, not a separate tag-triggered build.

There is no npm publishing, package-version update, changelog commit, or bot
release commit. The private Node package only supplies pinned tooling. Use
Node.js 24 (at least 24.10.0) and `npm ci` with the committed lockfile. To resolve
an intentional tooling update, regenerate the lock with
`npm install --package-lock-only --ignore-scripts` and review it.

Before enabling publication, run the repository validation separately:

```sh
npm ci --ignore-scripts
uv run --frozen pytest
npx semantic-release --dry-run
```

Also parse/review the workflow YAML. A semantic-release dry run needs the
release branches, baseline tag, full Git history, and suitable repository
authentication; it skips `prepare`, so it does not validate firmware bundles.
Do not place tokens in command lines or commit them to the repository.

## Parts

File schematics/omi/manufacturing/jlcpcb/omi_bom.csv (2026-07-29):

Designator | Comment | Footprint | LCSC
AE1 | 2450AT18A100E | JLC-MCP:ANT-SMD_L3.2-W1.6 | C89334
C23 | 4.7uF | Capacitor_SMD:C_0805_2012Metric | C76639
C24 | 100nF | Capacitor_SMD:C_0603_1608Metric | C108079
C25 | 100nF | Capacitor_SMD:C_0603_1608Metric | C108079
C26 | 100nF | Capacitor_SMD:C_0603_1608Metric | C108079
C27 | 100nF DEC1 | Capacitor_SMD:C_0603_1608Metric | C108079
C28 | 100nF DEC2 | Capacitor_SMD:C_0603_1608Metric | C108079
C29 | 100pF DEC3 | Capacitor_SMD:C_0603_1608Metric | C14665
C30 | 1uF DEC4 | Capacitor_SMD:C_0603_1608Metric | C113807
C31 | 1uF DEC5 | Capacitor_SMD:C_0603_1608Metric | C113807
C32 | 1uF DEC6 | Capacitor_SMD:C_0603_1608Metric | C113807
C33 | 4.7uF DECUSB | Capacitor_SMD:C_0805_2012Metric | C76639
C34 | 12pF | Capacitor_SMD:C_0603_1608Metric | C107034
C35 | 12pF | Capacitor_SMD:C_0603_1608Metric | C107034
C36 | 20pF | Capacitor_SMD:C_0603_1608Metric | C325469
C37 | 20pF | Capacitor_SMD:C_0603_1608Metric | C325469
C38 | 100nF | Capacitor_SMD:C_0603_1608Metric | C108079
C39 | 10uF | Capacitor_SMD:C_0805_2012Metric | C380331
C42 | 1uF | Capacitor_SMD:C_0603_1608Metric | C113807
C43 | 4.7uF | Capacitor_SMD:C_0805_2012Metric | C76639
C44 | 4.7uF | Capacitor_SMD:C_0805_2012Metric | C76639
C45 | 10uF 6.3V X5R | Capacitor_SMD:C_0805_2012Metric | C380331
C46 | 10uF 6.3V X5R | Capacitor_SMD:C_0805_2012Metric | C380331
C47 | 100nF | Capacitor_SMD:C_0603_1608Metric | C108079
C48 | 22uF 6.3V X5R | Capacitor_SMD:C_0805_2012Metric | C380336
C49 | 22uF 6.3V X5R | Capacitor_SMD:C_0805_2012Metric | C380336
C50 | 22uF 6.3V X5R | Capacitor_SMD:C_0805_2012Metric | C380336
C51 | 1uF | Capacitor_SMD:C_0603_1608Metric | C113807
C52 | 1.0pF C0G RF (Nordic ref) | Capacitor_SMD:C_0201_0603Metric | C85893
C53 | 2.0pF C0G RF (Nordic ref) | Capacitor_SMD:C_0201_0603Metric | C88875
C54 | 1.0pF C0G RF (Nordic ref) | Capacitor_SMD:C_0201_0603Metric | C85893
C55 | 100nF | Capacitor_SMD:C_0603_1608Metric | C108079
C56 | 10uF | Capacitor_SMD:C_0805_2012Metric | C380331
C57 | 100nF | Capacitor_SMD:C_0603_1608Metric | C108079
C58 | 10uF | Capacitor_SMD:C_0805_2012Metric | C380331
C59 | 100nF | Capacitor_SMD:C_0603_1608Metric | C108079
C60 | 10uF | Capacitor_SMD:C_0805_2012Metric | C380331
C61 | 2.2uF | Capacitor_SMD:C_0603_1608Metric | C513691
C62 | 2.2uF | Capacitor_SMD:C_0603_1608Metric | C513691
C63 | 100nF | Capacitor_SMD:C_0603_1608Metric | C108079
C64 | 2.2nF C0G | Capacitor_SMD:C_0603_1608Metric | C107043
C65 | 2.2nF C0G | Capacitor_SMD:C_0603_1608Metric | C107043
C66 | 1uF | Capacitor_SMD:C_0603_1608Metric | C113807
C67 | 1uF | Capacitor_SMD:C_0603_1608Metric | C113807
C68 | 1uF | Capacitor_SMD:C_0603_1608Metric | C113807
C69 | 1uF | Capacitor_SMD:C_0603_1608Metric | C113807
C70 | 2.2uF | Capacitor_SMD:C_0603_1608Metric | C513691
C71 | 2.2uF | Capacitor_SMD:C_0603_1608Metric | C513691
C72 | 100nF | Capacitor_SMD:C_0603_1608Metric | C108079
C73 | 100nF | Capacitor_SMD:C_0603_1608Metric | C108079
C74 | 1uF | Capacitor_SMD:C_0603_1608Metric | C113807
C75 | 470nF | Capacitor_SMD:C_0603_1608Metric | C1623
C76 | 2.2uF | Capacitor_SMD:C_0603_1608Metric | C513691
C77 | 68nF | Capacitor_SMD:C_0603_1608Metric | C107071
C78 | 100nF C0G | Capacitor_SMD:C_1206_3216Metric | C170182
C79 | 1uF | Capacitor_SMD:C_0603_1608Metric | C113807
D1 | PESD5V0S1UL CC1 | JLC-MCP:SOD-882_L1.0-W0.6-RD | C85402
D2 | PESD5V0S1UL CC2 | JLC-MCP:SOD-882_L1.0-W0.6-RD | C85402
D3 | SMF5.0A VBUS TVS | JLC-MCP:SOD-123F_L2.8-W1.8-LS3.7-RD | C151296
J3 | NRF SWD RECOVERY | Connector:Tag-Connect_TC2030-IDC-NL_2x03_P1.27mm_Vertical | Not stocked - factory fixture
J4 | USB-C | Connector_USB:USB_C_Receptacle_HRO_TYPE-C-31-M-12 | C165948
J5 | LiPo + NTC | Connector_JST:JST_GH_BM03B-GHS-TBT_1x03-1MP_P1.25mm_Vertical | C161691
J6 | PJ-327C-4A Headphones | JLC-MCP:AUDIO-SMD_PJ-327C-4A | C145813
J7 | PJ-327C-4A Microphone | JLC-MCP:AUDIO-SMD_PJ-327C-4A | C145813
J8 | ESP FACTORY | Connector_PinHeader_2.54mm:PinHeader_1x06_P2.54mm_Vertical | C492405
L1 | 10uH >=100mA | Inductor_SMD:L_0603_1608Metric | C713281
L2 | XFL4020-152MEC 1.5uH | JLC-MCP:IND-SMD_L4.0-W4.0-A | C3033018
L3 | 1.9nH RF (Nordic ref) | Inductor_SMD:L_0201_0603Metric | C206445
L4 | 3.0nH RF (Nordic ref) | Inductor_SMD:L_0201_0603Metric | C98044
R12 | 0R antenna tune | Resistor_SMD:R_0201_0603Metric | C106228
R13 | 33R | Resistor_SMD:R_0603_1608Metric | C23140
R14 | 33R | Resistor_SMD:R_0603_1608Metric | C23140
R15 | 10k | Resistor_SMD:R_0603_1608Metric | C25804
R16 | 5.1k 1% | Resistor_SMD:R_0603_1608Metric | C23186
R17 | 5.1k 1% | Resistor_SMD:R_0603_1608Metric | C23186
R18 | 1.13k 1% | Resistor_SMD:R_0603_1608Metric | C22833
R19 | 4.12k 1% | Resistor_SMD:R_0603_1608Metric | C23041
R20 | 46.4k 1% | Resistor_SMD:R_0603_1608Metric | C23059
R22 | 1M 1% | Resistor_SMD:R_0603_1608Metric | C22935
R23 | 180k 1% | Resistor_SMD:R_0603_1608Metric | C22827
R24 | 1M | Resistor_SMD:R_0603_1608Metric | C22935
R25 | 10k | Resistor_SMD:R_0603_1608Metric | C25804
R26 | 10k | Resistor_SMD:R_0603_1608Metric | C25804
R27 | 49.9R 1% ANT2 termination | Resistor_SMD:R_0201_0603Metric | C155744
R28 | 33k FEM MODE | Resistor_SMD:R_0603_1608Metric | C4216
R29 | 470R | Resistor_SMD:R_0603_1608Metric | C23179
R30 | 470R | Resistor_SMD:R_0603_1608Metric | C23179
R31 | 18k | Resistor_SMD:R_0603_1608Metric | C25810
R32 | 18k | Resistor_SMD:R_0603_1608Metric | C25810
R33 | 100k | Resistor_SMD:R_0603_1608Metric | C25803
R34 | 150k | Resistor_SMD:R_0603_1608Metric | C22807
R35 | 100k | Resistor_SMD:R_0603_1608Metric | C25803
R36 | 2.2k | Resistor_SMD:R_0603_1608Metric | C4190
R37 | 100k | Resistor_SMD:R_0603_1608Metric | C25803
R38 | 22R USB D- | Resistor_SMD:R_0603_1608Metric | C23345
R39 | 22R USB D+ | Resistor_SMD:R_0603_1608Metric | C23345
R40 | 100k USB100 default | Resistor_SMD:R_0603_1608Metric | C25803
R41 | 100k EN pulldown | Resistor_SMD:R_0603_1608Metric | C25803
R42 | 0R SHIELD BOND | Resistor_SMD:R_0603_1608Metric | C21189
SW1 | ESP RESET | Button_Switch_SMD:SW_Push_1P1T_XKB_TS-1187A | C318884
SW2 | ESP BOOT | Button_Switch_SMD:SW_Push_1P1T_XKB_TS-1187A | C318884
SW3 | POWER ON/OFF | Button_Switch_SMD:SW_SPDT_Shouhan_MSK12C02 | C431540
U1 | ESP32-S3-WROOM-1 | RF_Module:ESP32-S3-WROOM-1 | C2913198
U2 | NRF52840-QIAA-R | JLC-MCP:AQFN-73_L7.0-W7.0-P0.50-BL-EP4.8 | C190794
U3 | NRF21540-QDAA-R | JLC-MCP:QFN-16_L4.0-W4.0-P0.65-BL-EP2.7 | C1518188
U4 | BQ24074RGTR | JLC-MCP:QFN-16_L3.0-W3.0-P0.50-TL-EP1.7 | C54313
U5 | TPS63020DSJR | JLC-MCP:VSON-14_L4.0-W3.0-P0.50-BL-EP_TI_DSJ | C15483
U6 | USBLC6-2SC6 | JLC-MCP:SOT-23-6_L2.9-W1.6-P0.95-LS2.8-BL | C7519
U7 | PCM5102APWR | JLC-MCP:TSSOP-20_L6.5-W4.4-P0.65-LS6.4-BL | C107671
U8 | MAX9814ETD+T | JLC-MCP:TDFN-14_L3.0-W3.0-P0.40-BL-EP | C41714
U9 | TPA6132A2RTER | JLC-MCP:WQFN-16_L3.0-W3.0-P0.50-TL-EP1.6 | C69901
Y1 | 32MHz 8pF | JLC-MCP:CRYSTAL-SMD_4P-L3.2-W2.5-BL | C426985
Y2 | 32.768kHz 12.5pF | JLC-MCP:OSC-SMD_L3.2-W1.5 | C97606

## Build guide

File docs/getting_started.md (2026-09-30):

# Getting Started

The tested setup uses two ESP32-S31 Function CoreBoard-1 / XIAO nRF52840 Sense pairs.
The S31 handles audio and Bluetooth; the nRF provides the ESB mesh radio.

## Hardware and Tools

For each pair, use:

- An ESP32-S31 Function CoreBoard-1 with 16 MB flash and 16 MB PSRAM.
- A XIAO nRF52840 Sense and a passive 4 ohm, 3 W speaker.
- Three normally-open momentary buttons, data-capable USB cables, and the connections in [wiring.md](wiring.md).

The CoreBoard already contains the microphone, codec, and speaker amplifier.
Do not add the external audio modules from the older ESP32-S3 prototype.

The commands below assume Linux, Docker access, and a cloned repository.
Install `uv` for the benchmark and Python tests, and NCS 3.4.1 with its matching toolchain for the nRF build.

## Build the S31 Firmware

Run from the repository root. Use the pinned ESP-IDF preview image that supports S31:

```bash
export IDF_IMAGE=espressif/idf@sha256:8ac794c57fd4cac246cb8d2ada4002fa26337ac7df683047b5b83743dbedb6b7

docker run --rm --user "$(id -u):$(id -g)" \
  -e HOME=/tmp -e OMI_ESP_LC3_BENCH=1 \
  -v "$PWD:/project" -w /project "$IDF_IMAGE" \
  bash -lc '. "$IDF_PATH/export.sh" >/dev/null &&
    idf.py --preview -B build-s31 \
      -D SDKCONFIG=/project/build-s31/sdkconfig \
      -D IDF_TARGET=esp32s31 \
      -D ESP_LC3_BENCH=ON \
      -D S31_LC3_WIRE=ON \
      -D S31_LC3_SELFTEST=ON \
      -D S31_LC3_SERIALIZE=ON \
      -D S31_LC3_INTERNAL_BUFFERS=ON \
      -D S31_LC3_SINGLE_OWNER=ON \
      -D S31_LC3_SPLIT_CORES=OFF \
      -D S31_LC3_SKIP_RX=OFF \
      -D S31_MESH_COEX_PREFER_WIFI=OFF \
      -D S31_MESH_PAIR_UNICAST=OFF \
      -D S31_TASK_CPU_PROFILE=OFF build'
```

Use a fresh `build-s31` directory for this configuration.
Its separate `sdkconfig` uses the project's defaults instead of an existing root configuration.
The environment variable and CMake options are both required for the LC3 dependency and codec path.
Plain `idf.py build` does not enable this configuration by default.

The pinned image contains ESP-IDF commit `9a97f6c54ec638111ce55cd36581b3c192f15207`.
Do not substitute a moving SDK tag when comparing results.

## Build the nRF Firmware

Open an NCS 3.4.1 toolchain terminal. From its SDK workspace, set the absolute path to this repository:

```bash
export OMI_APP_DIR=/absolute/path/to/omi

west build --sysbuild -b xiao_ble/nrf52840 \
  "$OMI_APP_DIR/nrf_mesh" -d "$OMI_APP_DIR/build-nrf341" \
  -- -DCONFIG_BUILD_OUTPUT_UF2=y
```

The tested target is also used for our XIAO Sense boards.
The application image is `build-nrf341/nrf_mesh/zephyr/zephyr.uf2`.
Both ends need matching LC3 firmware with bridge protocol 6; update the S31 and nRF together.

## Flash the Boards

### XIAO nRF52840

Power off the pair and disconnect the shared `3V3` supply wire before connecting XIAO USB.
Follow the [USB power and flashing procedure](wiring.md#usb-flashing-or-nrf-serial-capture).

Double-press XIAO RESET and copy the application UF2 to its bootloader drive.
The board restarts after the copy. Use the application UF2, not a whole-chip erase or bootloader replacement.
Repeat for the other nRF.

### ESP32-S31

Native USB JTAG/OpenOCD is the tested flashing path; serial flashing was unreliable on this setup.
Connect the S31's native USB port and select its USB serial identity explicitly.
Run from the repository root, using `IDF_IMAGE` from the build step:

```bash
export S31_SERIAL=YOUR_S31_USB_SERIAL

docker run --rm --user 0:0 \
  --device-cgroup-rule='c 189:* rwm' \
  -v /dev/bus/usb:/dev/bus/usb \
  -v "$PWD:/project:ro" -w /project \
  -e S31_SERIAL "$IDF_IMAGE" \
  bash -lc '. "$IDF_PATH/export.sh" >/dev/null &&
    openocd -f board/esp32s31-builtin.cfg \
      -c "adapter serial $S31_SERIAL" \
      -c "program_esp_bins /project/build-s31 flasher_args.json verify reset exit"'
```

This uses the generated image list and offsets for the bootloader, partition table, and application.
An app-only update is not sufficient for initial board setup. Check the programming and verification results before continuing.
Repeat with the other S31's serial identity.

## First Checks

1. Let each nRF boot, then reset its S31 so the SPI probe can find it.
2. Confirm nRF ESB selection, bridge protocol 5, LC3, and 20 ms audio in the S31 logs.
3. On each fresh S31, hold the external center/play button for 2 to under 6 seconds, then release it to enable mesh.
4. Confirm that the two nodes join the same mesh and report a peer.
5. Speak near each microphone and listen at the opposite speaker.
6. Use the [external button controls](buttons.md) to pair a phone, select a talk channel, and test music alongside mesh voice.

With VOX enabled, silence stops LC3 encoding and audio transmission after the hangover period.
Capture and control traffic continue; quiet audio counters alone are not a fault.
There is no pre-roll buffer, so the start of quiet speech can be clipped.

An absent or incompatible nRF bridge causes ESP-NOW fallback at startup.
Check the selected transport before comparing results. With nRF selected, S31 Wi-Fi is off and Bluetooth remains enabled.

For normal one-cable operation, follow the power transition in [wiring.md](wiring.md) before reconnecting the shared supply.

## Capture Logs and Run Tests

From the repository root, select the actual serial ports:

```bash
uv run benchmark.py --duration 120 --baud 115200 \
  --ports /dev/ttyACM0 /dev/ttyACM1 --out-dir logs/benchmark

uv run --frozen pytest
```

Prefer stable `/dev/serial/by-id/` paths. Capture both S31s together; nRF USB consoles are optional additional inputs.
Disconnect the shared supply before adding nRF USB power. The current nRF console uses CDC interface `if02`.

Each run produces `raw/`, `report.txt`, and `summary.json`.
See [pipeline telemetry](pipeline_telemetry.md) for counter interpretation and [CPU profiling](s31-cpu-profiling.md) for optional diagnostics.
Standalone C checks and firmware build jobs are listed in [the CI workflow](../.github/workflows/build.yml).

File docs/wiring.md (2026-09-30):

# ESP32-S31 Function CoreBoard Wiring

This guide describes the bridge/audio wiring tested on two prototype pairs.

- ESP32-S31-Function-CoreBoard-1
- Seeed XIAO nRF52840 Sense running the `nrf_mesh` firmware
- One passive 4 ohm speaker on the CoreBoard speaker connector

The older ESP32-S3, MAX9814, PCM5102A, and MAX98357A prototype uses different
pins. Do not use its GPIO map with this firmware.

## External Buttons

Add three normally-open momentary switches. Connect one terminal of each switch
to its GPIO and the other to CoreBoard `J2` pin 8 (`G`, ground):

| Button | ESP32-S31 GPIO | CoreBoard J2 header pin | Other terminal |
| --- | ---: | ---: | --- |
| Minus | GPIO1 | pin 12 | `G` / pin 8 |
| Center / play | GPIO2 | pin 7 | `G` / pin 8 |
| Plus | GPIO3 | pin 10 | `G` / pin 8 |

These are **J2 header positions**, not module pad numbers. Check the J2 pin-1
marking and [Espressif's official J2 diagram](https://docs.espressif.com/projects/esp-dev-kits/en/latest/esp32s31/esp32-s31-function-coreboard-1/user_guide.html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)
before wiring, especially on third-party CoreBoard revisions.
See [buttons.md](buttons.md) for timing and actions.

## Onboard Audio

The CoreBoard already contains the microphone, ES8311 codec, and NS4150B speaker
amplifier. Do not connect external microphone, codec, or I2S amplifier modules.

Connect a passive 4 ohm, 3 W speaker to the CoreBoard speaker output.
The connector pitch is 1.25 mm. The amplifier output is differential, so neither
speaker terminal connects to ground.

<details>
<summary>Onboard audio GPIOs and WS clock details</summary>

The onboard audio signals are not exposed on `J2`:

| Function | ESP32-S31 GPIO |
|---|---:|
| ES8311 I2C SCL | 50 |
| ES8311 I2C SDA | 51 |
| I2S MCLK | 52 |
| I2S BCLK | 53 |
| I2S microphone data to ESP | 54 |
| I2S WS/LRCLK | 55 |
| I2S playback data to codec | 56 |
| NS4150B amplifier enable | 57 |

The firmware mirrors physical 48 kHz I2S WS to GPIO47, providing 960 rising edges
per 20 ms frame. This is separate from the 16 kHz mono LC3 audio rate.
Two 10 ms LC3 frames form each 20 ms mesh audio payload.

Connect the mirror to the nRF as shown below, not to the onboard codec WS net.
The wire provides a clock reference; its presence alone does not establish that
WS-based clock correction is enabled.

</details>

## nRF52840 Bridge

The nRF52840 is the SPI master. The ESP32-S31 is the SPI slave.
The bridge uses SPI mode 0 at 4 MHz with 256-byte full-duplex transactions.

Make these six signal connections:

| Function | XIAO nRF52840 | CoreBoard J2 | ESP32-S31 |
|---|---|---:|---:|
| ACK, nRF to ESP | D10 / P1.15 | pin 20 | GPIO42 |
| SPI MISO, ESP to nRF | D7 / P1.12 | pin 17 | GPIO43 |
| SPI MOSI, nRF to ESP | D6 / P1.11 | pin 18 | GPIO44 |
| SPI clock, nRF to ESP | D8 / P1.13 | pin 15 | GPIO45 |
| SPI chip select, nRF to ESP, active low | D9 / P1.14 | pin 16 | GPIO46 |
| I2S WS sync, ESP to nRF | D0 / P0.02 | pin 13 | GPIO47 (48 kHz mirror) |

Also connect ground:

| XIAO nRF52840 | CoreBoard J2 |
|---|---|
| GND | any `G` pin: 1, 2, 8, 33, 34, 37, or 38 |

The `D` labels identify XIAO pads; the J2 numbers identify CoreBoard connector positions.
Use the connector's pin-1 marking and the vendor header table to orient J2.

<details>
<summary>MISO direction and connection diagram</summary>

Signal direction matters. In particular, the wire named `MISO` carries data
from ESP GPIO43 to XIAO P1.12 because the nRF is the bus master.

```text
ESP32-S31 Function CoreBoard-1                 XIAO nRF52840 Sense

J2 pin 20 / GPIO42  <------------------------- D10 / P1.15   ACK
J2 pin 17 / GPIO43  --------------------------> D7 / P1.12    MISO
J2 pin 18 / GPIO44  <-------------------------- D6 / P1.11    MOSI
J2 pin 15 / GPIO45  <-------------------------- D8 / P1.13    SCLK
J2 pin 16 / GPIO46  <-------------------------- D9 / P1.14    CS
J2 pin 13 / GPIO47  --------------------------> D0 / P0.02    WS sync
J2 GND              --------------------------- GND
```

</details>

### Power

Both boards use 3.3 V logic. No level shifter is required.

#### Normal prototype operation: one USB cable per pair

The tested setup powers the XIAO from the USB-powered CoreBoard:

| CoreBoard | XIAO nRF52840 Sense |
|---|---|
| J2 pin 35 or 36, `3V3` | `3V3` pad |
| J2 `G` pin | GND |

This feeds the XIAO's 3.3 V rail directly; Seeed labels that pad `3V3_OUT`.
It describes the tested bench arrangement, not a dedicated XIAO power-input connector.

Power off both boards before connecting the supply wire. Leave XIAO USB and battery
power disconnected while this wire is fitted. Never connect USB `5V` or `VBUS` to a `3V3` pad.

The nRF runs without a USB host. Its USB connection is not required for SPI or mesh operation.

#### USB flashing or nRF serial capture

1. Power off the pair and disconnect any XIAO battery.
2. Disconnect the `3V3` wire between the boards. Keep the signal and ground wires connected.
3. Power each board from its own USB connector.
4. Double-press the XIAO's RESET button to enter its UF2 bootloader, then copy the application UF2.
5. Wait for the XIAO to restart before checking the SPI bridge.

For serial capture, use the nRF application console after it restarts, not the UF2 drive.
The current nRF firmware exposes two CDC interfaces; its console is on `if02`.

To return to one-cable operation, remove USB power from both boards before restoring the `3V3` wire.
Then connect USB only to the CoreBoard.

<details>
<summary>CoreBoard Pins to Avoid</summary>

- GPIO61 is the BOOT button and a strapping pin, not a runtime control on the new S31 firmware.
- GPIO60 drives the onboard RGB LED and is a strapping pin.
- GPIO37 is a strapping pin.
- GPIO58 and GPIO59 are UART0 through the onboard USB-to-UART bridge.
- GPIO20 through GPIO25 are the fixed SDIO slot-0 group.
- GPIO35 through GPIO40 are the fixed SDIO slot-1 group.
- GPIO33 and GPIO34 are the fixed USB Serial/JTAG data pins and are not on J2.
- GPIO26 through GPIO32 are reserved for flash and must not be used.

The bridge map uses GPIO42 through GPIO47 and avoids these conflicts.

</details>

For external-button gestures and voice prompts, see [Button controls](buttons.md).

## Bring-up Order

1. With power disconnected, connect ground, ACK, SPI, WS, the three buttons, and the speaker as shown above.
2. Use the separate-USB arrangement for flashing; leave the shared `3V3` wire disconnected.
3. Flash matching S31 and nRF firmware with bridge protocol v6 and LC3 support.
4. Let the XIAO boot, then reset the S31 so it can probe the bridge.
5. Confirm the S31 log selects nRF ESB and reports bridge protocol 6, LC3, and 20 ms audio frames.
6. Repeat for the second pair and confirm that the mesh reports a peer.
7. Speak near each microphone in turn and check the opposite speaker.

With VOX enabled, silent microphones do not produce LC3 audio packets. Control traffic
and mesh membership continue, so quiet audio counters alone do not indicate a wiring fault.

If the S31 selects ESP-NOW, check the nRF's power, firmware compatibility, and all six signal wires.
Also check common ground. An absent or incompatible bridge causes ESP-NOW fallback at startup.
When nRF ESB is selected, ESP Wi-Fi and ESP-NOW are disabled; Bluetooth remains available.

## Source References

- [ESP32-S31 Function CoreBoard-1 user guide](https://docs.espressif.com/projects/esp-dev-kits/en/latest/esp32s31/esp32-s31-function-coreboard-1/user_guide.html)
- [ESP32-S31 Function CoreBoard-1 schematic](https://dl.espressif.com/schematics/esp32-s31-function-coreboard-1-schematics.pdf)
- [Seeed XIAO nRF52840 Sense pin map](https://wiki.seeedstudio.com/XIAO_BLE/#xiao-nrf52840-sense-front)
- [S31 firmware pin definitions](../components/board/include/omi_board_pins.h)
- [nRF SPI pin configuration](../nrf_mesh/boards/xiao_ble.overlay)
- [nRF ACK and bridge configuration](../nrf_mesh/include/uart_bridge.h)
- [nRF WS input configuration](../nrf_mesh/src/ws_sync.c)

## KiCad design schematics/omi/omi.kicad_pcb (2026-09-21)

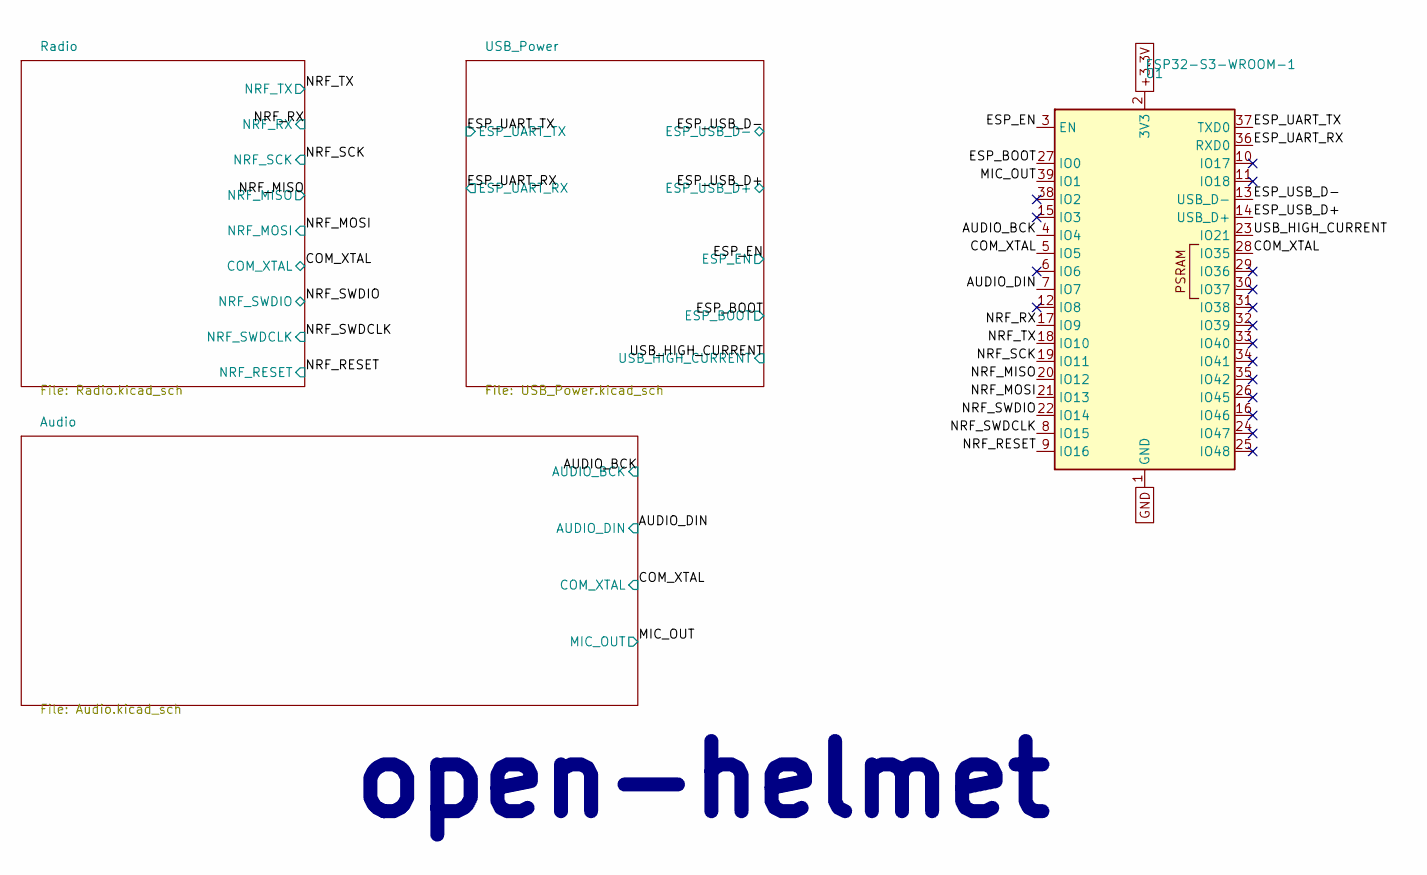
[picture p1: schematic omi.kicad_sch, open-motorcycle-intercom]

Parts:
U1: ESP32-S3-WROOM-1; MNF PART NUMBER ESP32-S3-WROOM-1-N8; LCSC C2913198

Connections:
+3.3V: U1.2 (3V3); also elsewhere on the board
/AUDIO_BCK: U1.4 (IO4); also elsewhere on the board
/AUDIO_DIN: U1.7 (IO7); also elsewhere on the board
/COM_XTAL: U1.5 (IO5), U1.28 (IO35); also elsewhere on the board
/ESP_BOOT: U1.27 (IO0); also elsewhere on the board
/ESP_EN: U1.3 (EN); also elsewhere on the board
/ESP_UART_RX: U1.36 (RXD0); also elsewhere on the board
/ESP_UART_TX: U1.37 (TXD0); also elsewhere on the board
/ESP_USB_D+: U1.14 (USB_D+); also elsewhere on the board
/ESP_USB_D-: U1.13 (USB_D-); also elsewhere on the board
/MIC_OUT: U1.39 (IO1); also elsewhere on the board
/NRF_MISO: U1.20 (IO12); also elsewhere on the board
/NRF_MOSI: U1.21 (IO13); also elsewhere on the board
/NRF_RESET: U1.9 (IO16); also elsewhere on the board
/NRF_RX: U1.17 (IO9); also elsewhere on the board
/NRF_SCK: U1.19 (IO11); also elsewhere on the board
/NRF_SWDCLK: U1.8 (IO15); also elsewhere on the board
/NRF_SWDIO: U1.22 (IO14); also elsewhere on the board
/NRF_TX: U1.18 (IO10); also elsewhere on the board
/USB_HIGH_CURRENT: U1.23 (IO21); also elsewhere on the board
GND: U1.1 (GND), U1.40 (GND), U1.41 (GND); also elsewhere on the board

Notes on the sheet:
open-helmet

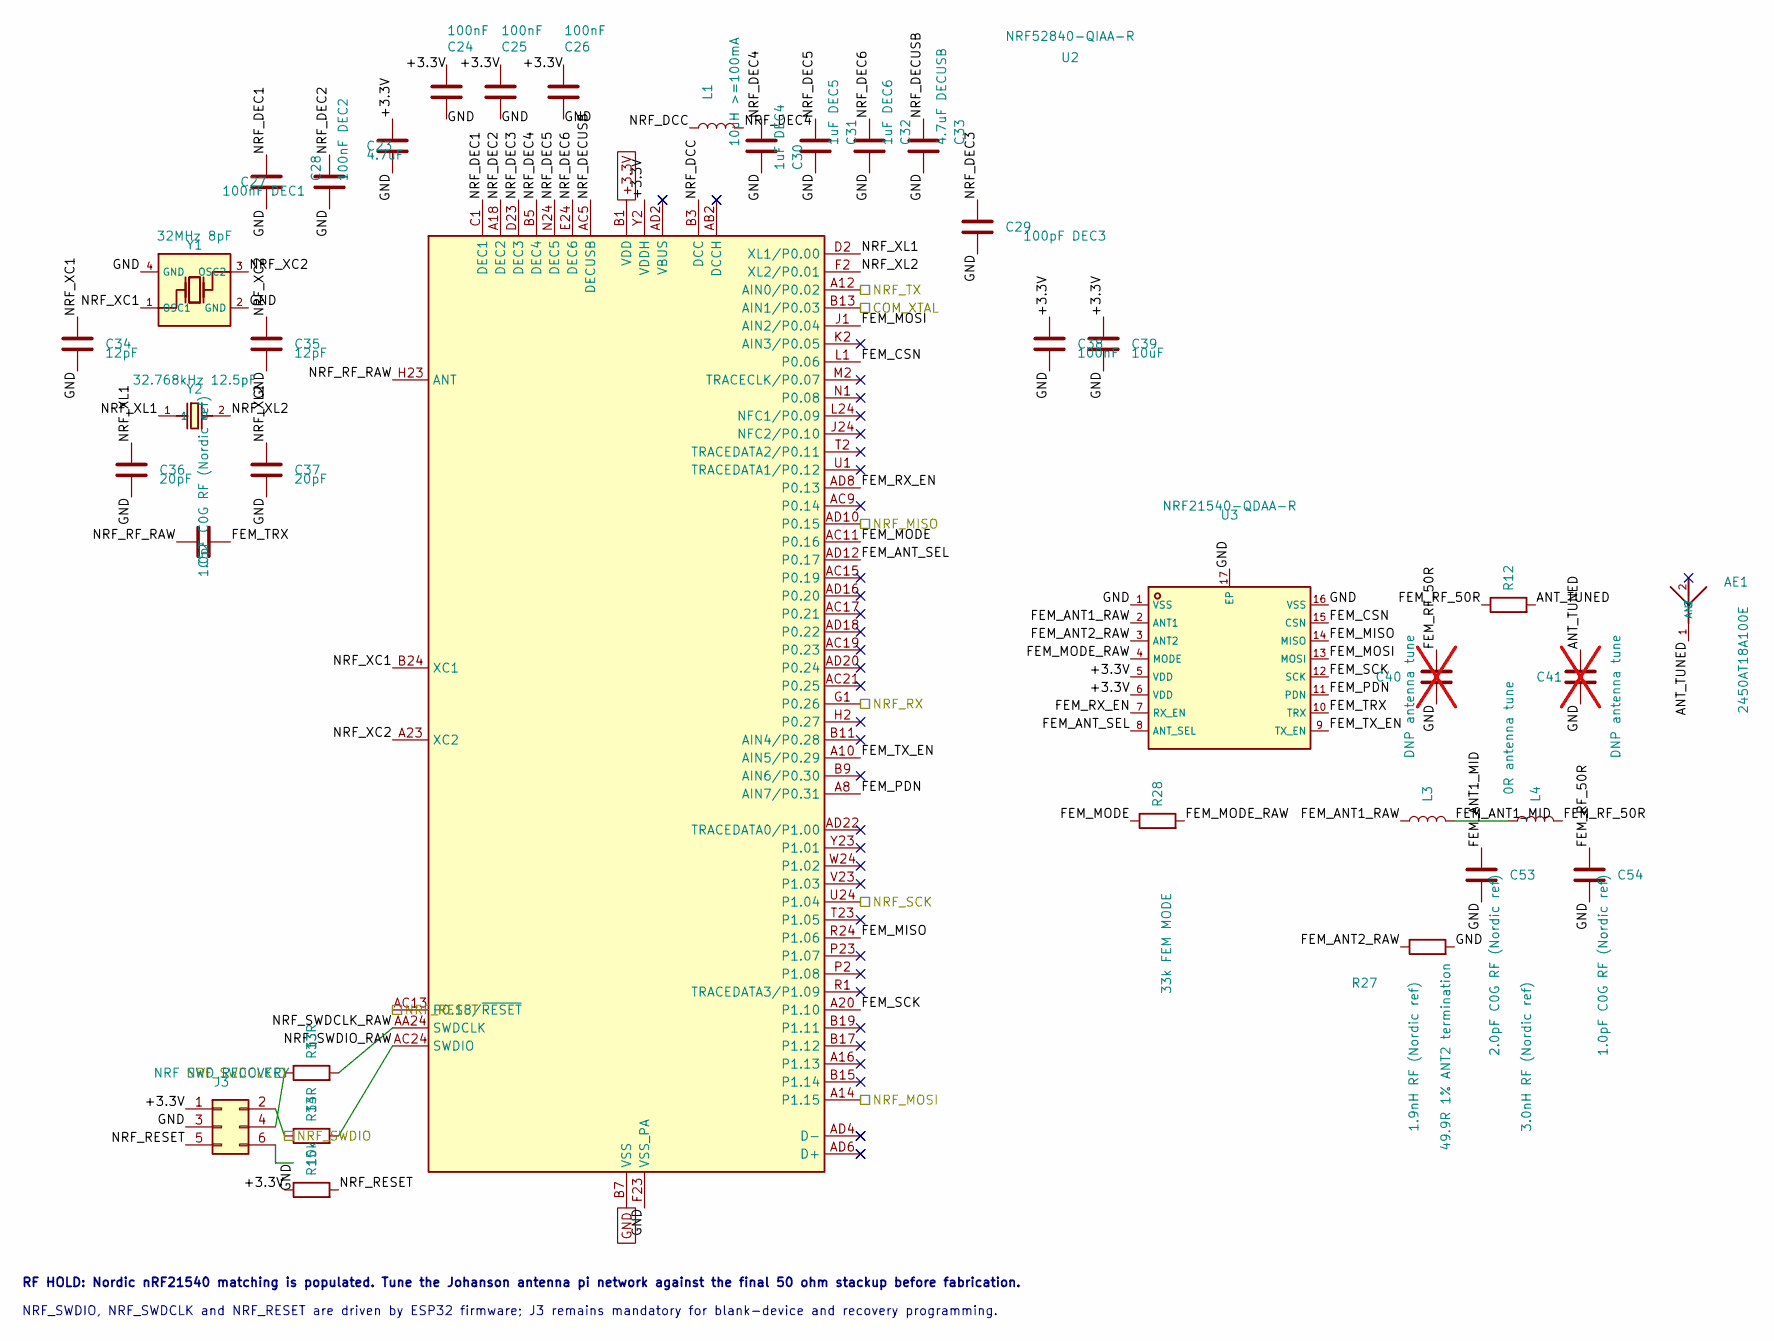
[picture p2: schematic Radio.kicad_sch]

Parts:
AE1: 2450AT18A100E; ANT-SMD_L3.2-W1.6; MNF PART NUMBER 2450AT18A100E; LCSC C89334
C23: 4.7uF; C_0805_2012Metric; MNF PART NUMBER C2012X7R1A475KT000N; LCSC C76639
C24, C25, C26, C38: 100nF; C_0603_1608Metric; MNF PART NUMBER CC0603KRX7R7BB104; LCSC C108079
C27: 100nF DEC1; C_0603_1608Metric; MNF PART NUMBER CC0603KRX7R7BB104; LCSC C108079
C28: 100nF DEC2; C_0603_1608Metric; MNF PART NUMBER CC0603KRX7R7BB104; LCSC C108079
C29: 100pF DEC3; C_0603_1608Metric; MNF PART NUMBER CC0603JRNPO9BN101; LCSC C14665
C30: 1uF DEC4; C_0603_1608Metric; MNF PART NUMBER CC0603KRX7R6BB105; LCSC C113807
C31: 1uF DEC5; C_0603_1608Metric; MNF PART NUMBER CC0603KRX7R6BB105; LCSC C113807
C32: 1uF DEC6; C_0603_1608Metric; MNF PART NUMBER CC0603KRX7R6BB105; LCSC C113807
C33: 4.7uF DECUSB; C_0805_2012Metric; MNF PART NUMBER C2012X7R1A475KT000N; LCSC C76639
C34, C35: 12pF; C_0603_1608Metric; MNF PART NUMBER CC0603JRNPO9BN120; LCSC C107034
C36, C37: 20pF; C_0603_1608Metric; MNF PART NUMBER CC0603GRNPO9BN200; LCSC C325469
C39: 10uF; C_0805_2012Metric; Voltage 10V; MNF PART NUMBER TCC0805X5R106K100FT; LCSC C380331
C40, C41: DNP antenna tune; C_0201_0603Metric; not fitted
C52, C54: 1.0pF C0G RF (Nordic ref); C_0201_0603Metric; MNF PART NUMBER GRM0335C1H1R0BA01D; LCSC C85893
C53: 2.0pF C0G RF (Nordic ref); C_0201_0603Metric; MNF PART NUMBER GJM0335C1E2R0BB01D; LCSC C88875
J3: NRF SWD RECOVERY; Tag-Connect_TC2030-IDC-NL_2x03_P1.27mm_Vertical; MNF PART NUMBER TC2030-IDC-NL; LCSC Not stocked - factory fixture
L1: 10uH >=100mA; L_0603_1608Metric; MNF PART NUMBER LQM18DN100M70L; LCSC C713281
L3: 1.9nH RF (Nordic ref); L_0201_0603Metric; MNF PART NUMBER LQP03TN1N9B02D; LCSC C206445
L4: 3.0nH RF (Nordic ref); L_0201_0603Metric; MNF PART NUMBER LQP03TN3N0B02D; LCSC C98044
R12: 0R antenna tune; R_0201_0603Metric; MNF PART NUMBER RC0201JR-070RL; LCSC C106228
R13, R14: 33R; R_0603_1608Metric; MNF PART NUMBER 0603WAF330JT5E; LCSC C23140
R15: 10k; R_0603_1608Metric; MNF PART NUMBER 0603WAF1002T5E; LCSC C25804
R27: 49.9R 1% ANT2 termination; R_0201_0603Metric; MNF PART NUMBER RC0201FR-0749R9L; LCSC C155744
R28: 33k FEM MODE; R_0603_1608Metric; MNF PART NUMBER 0603WAF3302T5E; LCSC C4216
U2: NRF52840-QIAA-R; AQFN-73_L7.0-W7.0-P0.50-BL-EP4.8; MNF PART NUMBER NRF52840-QIAA-R; LCSC C190794
U3: NRF21540-QDAA-R; QFN-16_L4.0-W4.0-P0.65-BL-EP2.7; MNF PART NUMBER NRF21540-QDAA-R; LCSC C1518188
Y1: 32MHz 8pF; CRYSTAL-SMD_4P-L3.2-W2.5-BL; MNF PART NUMBER S3232000081040; LCSC C426985
Y2: 32.768kHz 12.5pF; OSC-SMD_L3.2-W1.5; MNF PART NUMBER SC-32S32.768kHz20PPM12.5pF; LCSC C97606

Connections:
+3.3V: C23.1, C24.1, C25.1, C26.1, C38.1, C39.1, J3.1, R15.1, U2.A22 (VDD), U2.AD14 (VDD), U2.AD23 (VDD), U2.B1 (VDD), U2.W1 (VDD), U2.Y2 (VDDH), U3.5 (VDD), U3.6 (VDD); also elsewhere on the board
/COM_XTAL: U2.B13 (AIN1/P0.03); also elsewhere on the board
/NRF_MISO: U2.AD10 (P0.15); also elsewhere on the board
/NRF_MOSI: U2.A14 (P1.15); also elsewhere on the board
/NRF_RESET: J3.5, R15.2, U2.AC13 (P0.18/~RESET); also elsewhere on the board
/NRF_RX: U2.G1 (P0.26); also elsewhere on the board
/NRF_SCK: U2.U24 (P1.04); also elsewhere on the board
/NRF_SWDCLK: J3.4, R13.1; also elsewhere on the board
/NRF_SWDIO: J3.2, R14.1; also elsewhere on the board
/NRF_TX: U2.A12 (AIN0/P0.02); also elsewhere on the board
/Radio/ANT_TUNED: AE1.1 (ANT_1), C41.1, R12.2
/Radio/FEM_ANT1_MID: C53.1, L3.2, L4.1
/Radio/FEM_ANT1_RAW: L3.1, U3.2 (ANT1)
/Radio/FEM_ANT2_RAW: R27.1, U3.3 (ANT2)
/Radio/FEM_ANT_SEL: U2.AD12 (P0.17), U3.8 (ANT_SEL)
/Radio/FEM_CSN: U2.L1 (P0.06), U3.15 (CSN)
/Radio/FEM_MISO: U2.R24 (P1.06), U3.14 (MISO)
/Radio/FEM_MODE: R28.1, U2.AC11 (P0.16)
/Radio/FEM_MODE_RAW: R28.2, U3.4 (MODE)
/Radio/FEM_MOSI: U2.J1 (AIN2/P0.04), U3.13 (MOSI)
/Radio/FEM_PDN: U2.A8 (AIN7/P0.31), U3.11 (PDN)
/Radio/FEM_RF_50R: C40.1, C54.1, L4.2, R12.1
/Radio/FEM_RX_EN: U2.AD8 (P0.13), U3.7 (RX_EN)
/Radio/FEM_SCK: U2.A20 (P1.10), U3.12 (SCK)
/Radio/FEM_TRX: C52.2, U3.10 (TRX)
/Radio/FEM_TX_EN: U2.A10 (AIN5/P0.29), U3.9 (TX_EN)
/Radio/NRF_DCC: L1.1, U2.B3 (DCC)
/Radio/NRF_DEC1: C27.1, U2.C1 (DEC1)
/Radio/NRF_DEC2: C28.1, U2.A18 (DEC2)
/Radio/NRF_DEC3: C29.1, U2.D23 (DEC3)
/Radio/NRF_DEC4: C30.1, L1.2, U2.B5 (DEC4)
/Radio/NRF_DEC5: C31.1, U2.N24 (DEC5)
/Radio/NRF_DEC6: C32.1, U2.E24 (DEC6)
/Radio/NRF_DECUSB: C33.1, U2.AC5 (DECUSB)
/Radio/NRF_RF_RAW: C52.1, U2.H23 (ANT)
/Radio/NRF_SWDCLK_RAW: R13.2, U2.AA24 (SWDCLK)
/Radio/NRF_SWDIO_RAW: R14.2, U2.AC24 (SWDIO)
/Radio/NRF_XC1: C34.1, U2.B24 (XC1), Y1.1 (OSC1)
/Radio/NRF_XC2: C35.1, U2.A23 (XC2), Y1.3 (OSC2)
/Radio/NRF_XL1: C36.1, U2.D2 (XL1/P0.00), Y2.1
/Radio/NRF_XL2: C37.1, U2.F2 (XL2/P0.01), Y2.2
GND: C23.2, C24.2, C25.2, C26.2, C27.2, C28.2, C29.2, C30.2, C31.2, C32.2, C33.2, C34.2, C35.2, C36.2, C37.2, C38.2, C39.2, C40.2, C41.2, C53.2, C54.2, J3.3, J3.6, R27.2, U2.B7 (VSS), U2.EP (VSS), U2.F23 (VSS_PA), U3.1 (VSS), U3.16 (VSS), U3.17 (EP), Y1.2 (GND), Y1.4 (GND); also elsewhere on the board

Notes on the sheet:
RF HOLD: Nordic nRF21540 matching is populated. Tune the Johanson antenna pi network against the final 50 ohm stackup before fabrication.
NRF_SWDIO, NRF_SWDCLK and NRF_RESET are driven by ESP32 firmware; J3 remains mandatory for blank-device and recovery programming.

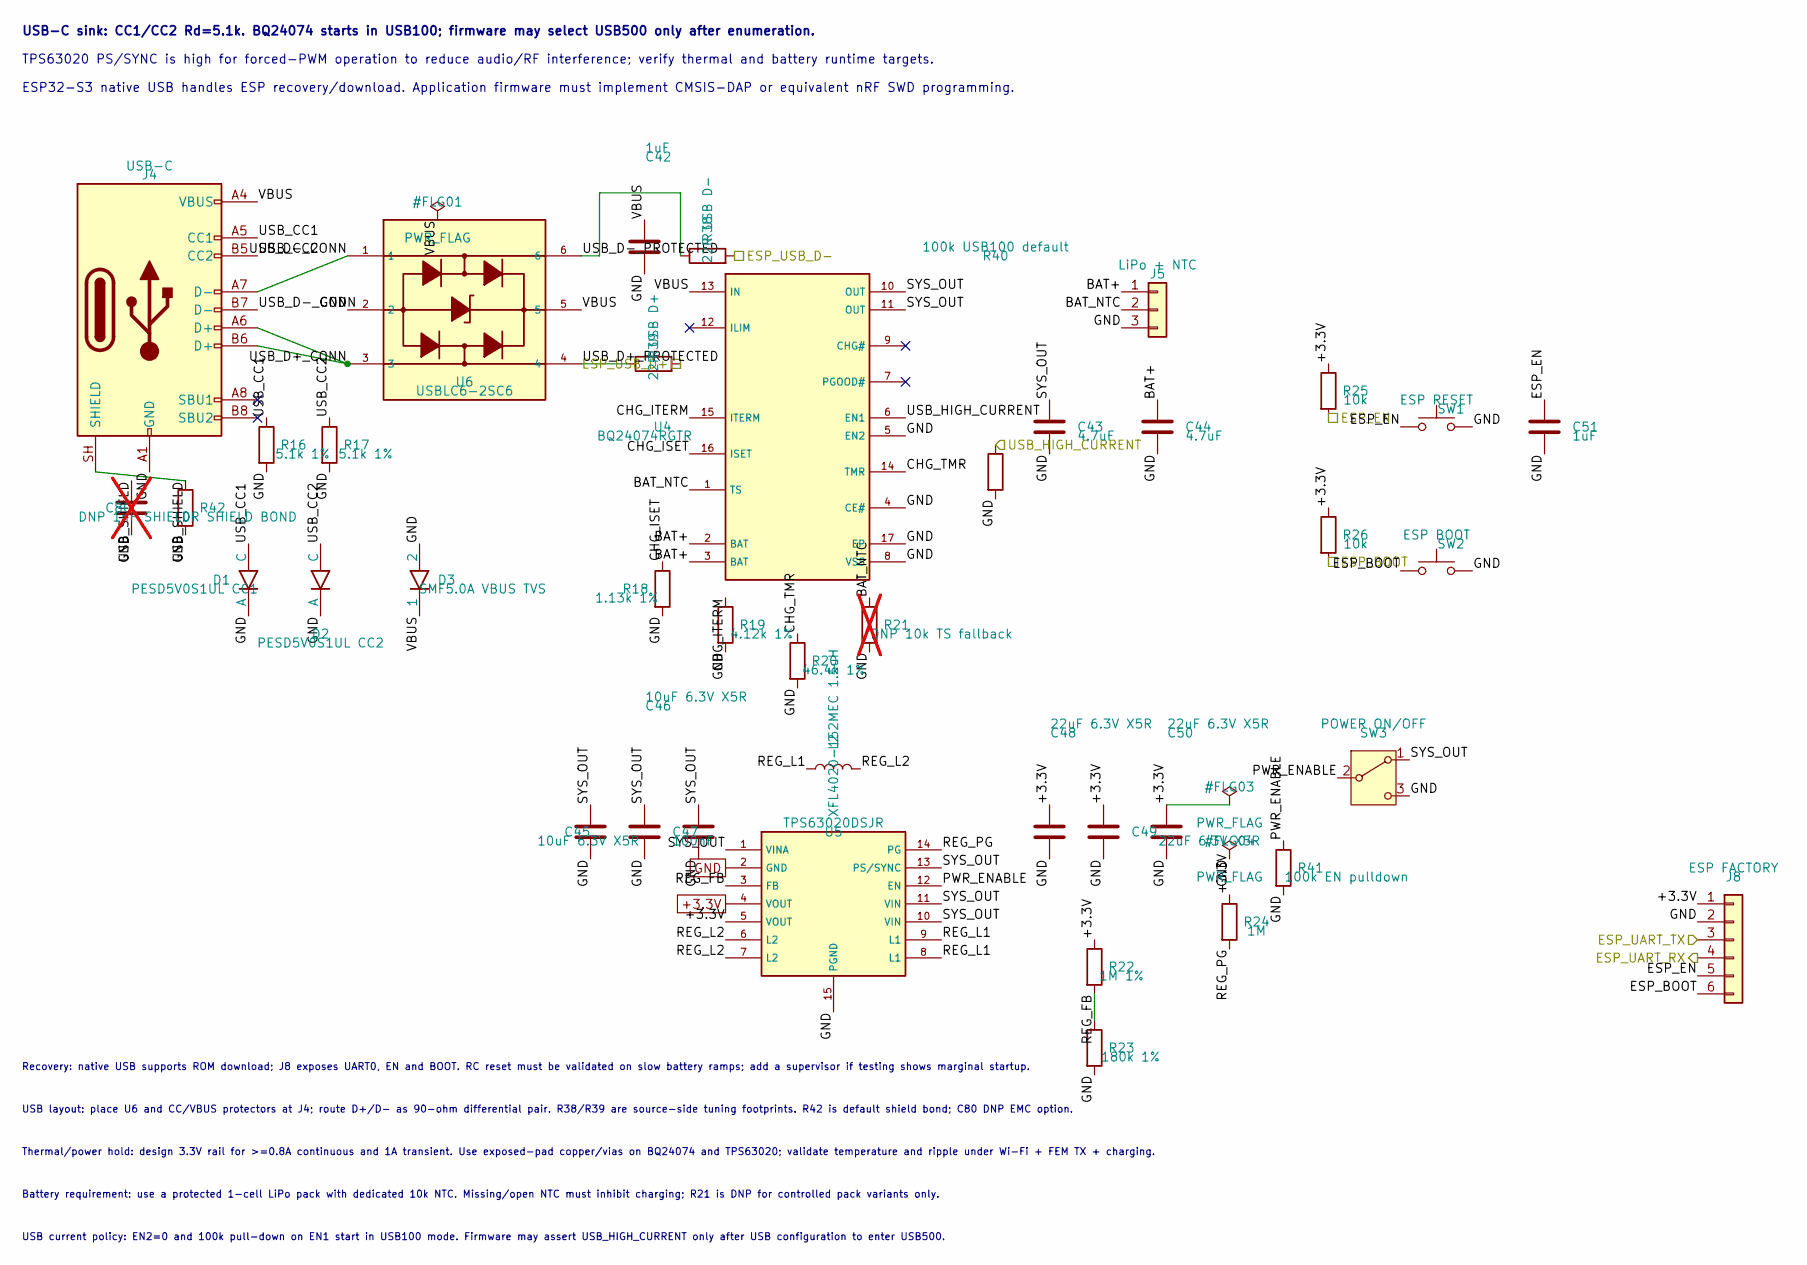
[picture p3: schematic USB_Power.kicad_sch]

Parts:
C42, C51: 1uF; C_0603_1608Metric; MNF PART NUMBER CC0603KRX7R6BB105; LCSC C113807
C43, C44: 4.7uF; C_0805_2012Metric; MNF PART NUMBER C2012X7R1A475KT000N; LCSC C76639
C45, C46: 10uF 6.3V X5R; C_0805_2012Metric; MNF PART NUMBER TCC0805X5R106K100FT; LCSC C380331
C47: 100nF; C_0603_1608Metric; MNF PART NUMBER CC0603KRX7R7BB104; LCSC C108079
C48, C49, C50: 22uF 6.3V X5R; C_0805_2012Metric; MNF PART NUMBER TCC0805X5R226K100FT; LCSC C380336
C80: DNP 1nF SHIELD; C_0603_1608Metric; MNF PART NUMBER TBD EMC tuning; not fitted
D1: PESD5V0S1UL CC1; SOD-882_L1.0-W0.6-RD; MNF PART NUMBER PESD5V0S1UL,315; LCSC C85402
D2: PESD5V0S1UL CC2; SOD-882_L1.0-W0.6-RD; MNF PART NUMBER PESD5V0S1UL,315; LCSC C85402
D3: SMF5.0A VBUS TVS; SOD-123F_L2.8-W1.8-LS3.7-RD; MNF PART NUMBER SMF5.0A; LCSC C151296
J4: USB-C; USB_C_Receptacle_HRO_TYPE-C-31-M-12; MNF PART NUMBER TYPE-C-31-M-12; LCSC C165948
J5: LiPo + NTC; JST_GH_BM03B-GHS-TBT_1x03-1MP_P1.25mm_Vertical; MNF PART NUMBER BM03B-GHS-TBT(LF)(SN); LCSC C161691
J8: ESP FACTORY; PinHeader_1x06_P2.54mm_Vertical; MNF PART NUMBER PZ254V-11-06P; LCSC C492405
L2: XFL4020-152MEC 1.5uH; IND-SMD_L4.0-W4.0-A; MNF PART NUMBER XFL4020-152MEC; LCSC C3033018
R16, R17: 5.1k 1%; R_0603_1608Metric; MNF PART NUMBER 0603WAF5101T5E; LCSC C23186
R18: 1.13k 1%; R_0603_1608Metric; MNF PART NUMBER 0603WAF1131T5E; LCSC C22833
R19: 4.12k 1%; R_0603_1608Metric; MNF PART NUMBER 0603WAF4121T5E; LCSC C23041
R20: 46.4k 1%; R_0603_1608Metric; MNF PART NUMBER 0603WAF4642T5E; LCSC C23059
R21: DNP 10k TS fallback; R_0603_1608Metric; MNF PART NUMBER 0603WAF1002T5E; LCSC C25804; not fitted
R22: 1M 1%; R_0603_1608Metric; MNF PART NUMBER 0603WAF1004T5E; LCSC C22935
R23: 180k 1%; R_0603_1608Metric; MNF PART NUMBER 0603WAF1803T5E; LCSC C22827
R24: 1M; R_0603_1608Metric; MNF PART NUMBER 0603WAF1004T5E; LCSC C22935
R25, R26: 10k; R_0603_1608Metric; MNF PART NUMBER 0603WAF1002T5E; LCSC C25804
R38: 22R USB D-; R_0603_1608Metric; MNF PART NUMBER 0603WAF220JT5E; LCSC C23345
R39: 22R USB D+; R_0603_1608Metric; MNF PART NUMBER 0603WAF220JT5E; LCSC C23345
R40: 100k USB100 default; R_0603_1608Metric; MNF PART NUMBER 0603WAF1003T5E; LCSC C25803
R41: 100k EN pulldown; R_0603_1608Metric; MNF PART NUMBER 0603WAF1003T5E; LCSC C25803
R42: 0R SHIELD BOND; R_0603_1608Metric; MNF PART NUMBER 0603WAF0000T5E; LCSC C21189
SW1: ESP RESET; SW_Push_1P1T_XKB_TS-1187A; MNF PART NUMBER TS-1187A-B-A-B; LCSC C318884
SW2: ESP BOOT; SW_Push_1P1T_XKB_TS-1187A; MNF PART NUMBER TS-1187A-B-A-B; LCSC C318884
SW3: POWER ON/OFF; SW_SPDT_Shouhan_MSK12C02; MNF PART NUMBER MSK12C02; LCSC C431540
U4: BQ24074RGTR; QFN-16_L3.0-W3.0-P0.50-TL-EP1.7; MNF PART NUMBER BQ24074RGTR; LCSC C54313
U5: TPS63020DSJR; VSON-14_L4.0-W3.0-P0.50-BL-EP_TI_DSJ; MNF PART NUMBER TPS63020DSJR; LCSC C15483
U6: USBLC6-2SC6; SOT-23-6_L2.9-W1.6-P0.95-LS2.8-BL; MNF PART NUMBER TYPE-C-31-M-12; LCSC C7519

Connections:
+3.3V: C48.1, C49.1, C50.1, J8.1, R22.1, R24.1, R25.1, R26.1, U5.4 (VOUT), U5.5 (VOUT); also elsewhere on the board
/ESP_BOOT: J8.6, R26.2, SW2.1; also elsewhere on the board
/ESP_EN: C51.1, J8.5, R25.2, SW1.1; also elsewhere on the board
/ESP_UART_RX: J8.4; also elsewhere on the board
/ESP_UART_TX: J8.3; also elsewhere on the board
/ESP_USB_D+: R39.2; also elsewhere on the board
/ESP_USB_D-: R38.2; also elsewhere on the board
/USB_HIGH_CURRENT: R40.1, U4.6 (EN1); also elsewhere on the board
/USB_Power/BAT+: C44.1, J5.1, U4.2 (BAT), U4.3 (BAT)
/USB_Power/BAT_NTC: J5.2, R21.1, U4.1 (TS)
/USB_Power/CHG_ISET: R18.1, U4.16 (ISET)
/USB_Power/CHG_ITERM: R19.1, U4.15 (ITERM)
/USB_Power/CHG_TMR: R20.1, U4.14 (TMR)
/USB_Power/PWR_ENABLE: R41.1, SW3.2 (B), U5.12 (EN)
/USB_Power/REG_FB: R22.2, R23.1, U5.3 (FB)
/USB_Power/REG_L1: L2.1, U5.8 (L1), U5.9 (L1)
/USB_Power/REG_L2: L2.2, U5.6 (L2), U5.7 (L2)
/USB_Power/REG_PG: R24.2, U5.14 (PG)
/USB_Power/SYS_OUT: C43.1, C45.1, C46.1, C47.1, SW3.1 (A), U4.10 (OUT), U4.11 (OUT), U5.1 (VINA), U5.10 (VIN), U5.11 (VIN), U5.13 (PS/SYNC)
/USB_Power/USB_CC1: D1.1 (C), J4.A5 (CC1), R16.1
/USB_Power/USB_CC2: D2.1 (C), J4.B5 (CC2), R17.1
/USB_Power/USB_D+_CONN: J4.A6 (D+), J4.B6 (D+), U6.3
/USB_Power/USB_D+_PROTECTED: R39.1, U6.4
/USB_Power/USB_D-_CONN: J4.A7 (D-), J4.B7 (D-), U6.1
/USB_Power/USB_D-_PROTECTED: R38.1, U6.6
/USB_Power/USB_SHIELD: C80.1, J4.SH (SHIELD), R42.1
/USB_Power/VBUS: C42.1, D3.1, J4.A4 (VBUS), J4.A9 (VBUS), J4.B4 (VBUS), J4.B9 (VBUS), U4.13 (IN), U6.5
GND: C42.2, C43.2, C44.2, C45.2, C46.2, C47.2, C48.2, C49.2, C50.2, C51.2, C80.2, D1.2 (A), D2.2 (A), D3.2, J4.A1 (GND), J4.A12 (GND), J4.B1 (GND), J4.B12 (GND), J5.3, J8.2, R16.2, R17.2, R18.2, R19.2, R20.2, R21.2, R23.2, R40.2, R41.2, R42.2, SW1.2, SW2.2, SW3.3 (C), U4.4 (CE#), U4.5 (EN2), U4.8 (VSS), U4.17 (EP), U5.2 (GND), U5.15 (PGND), U6.2; also elsewhere on the board

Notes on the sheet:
USB-C sink: CC1/CC2 Rd=5.1k. BQ24074 starts in USB100; firmware may select USB500 only after enumeration.
TPS63020 PS/SYNC is high for forced-PWM operation to reduce audio/RF interference; verify thermal and battery runtime targets.
ESP32-S3 native USB handles ESP recovery/download. Application firmware must implement CMSIS-DAP or equivalent nRF SWD programming.
USB current policy: EN2=0 and 100k pull-down on EN1 start in USB100 mode. Firmware may assert USB_HIGH_CURRENT only after USB configuration to enter USB500.
Battery requirement: use a protected 1-cell LiPo pack with dedicated 10k NTC. Missing/open NTC must inhibit charging; R21 is DNP for controlled pack variants only.
Thermal/power hold: design 3.3V rail for >=0.8A continuous and 1A transient. Use exposed-pad copper/vias on BQ24074 and TPS63020; validate temperature and ripple under Wi-Fi + FEM TX + charging.
USB layout: place U6 and CC/VBUS protectors at J4; route D+/D- as 90-ohm differential pair. R38/R39 are source-side tuning footprints. R42 is default shield bond; C80 DNP EMC option.
Recovery: native USB supports ROM download; J8 exposes UART0, EN and BOOT. RC reset must be validated on slow battery ramps; add a supervisor if testing shows marginal startup.

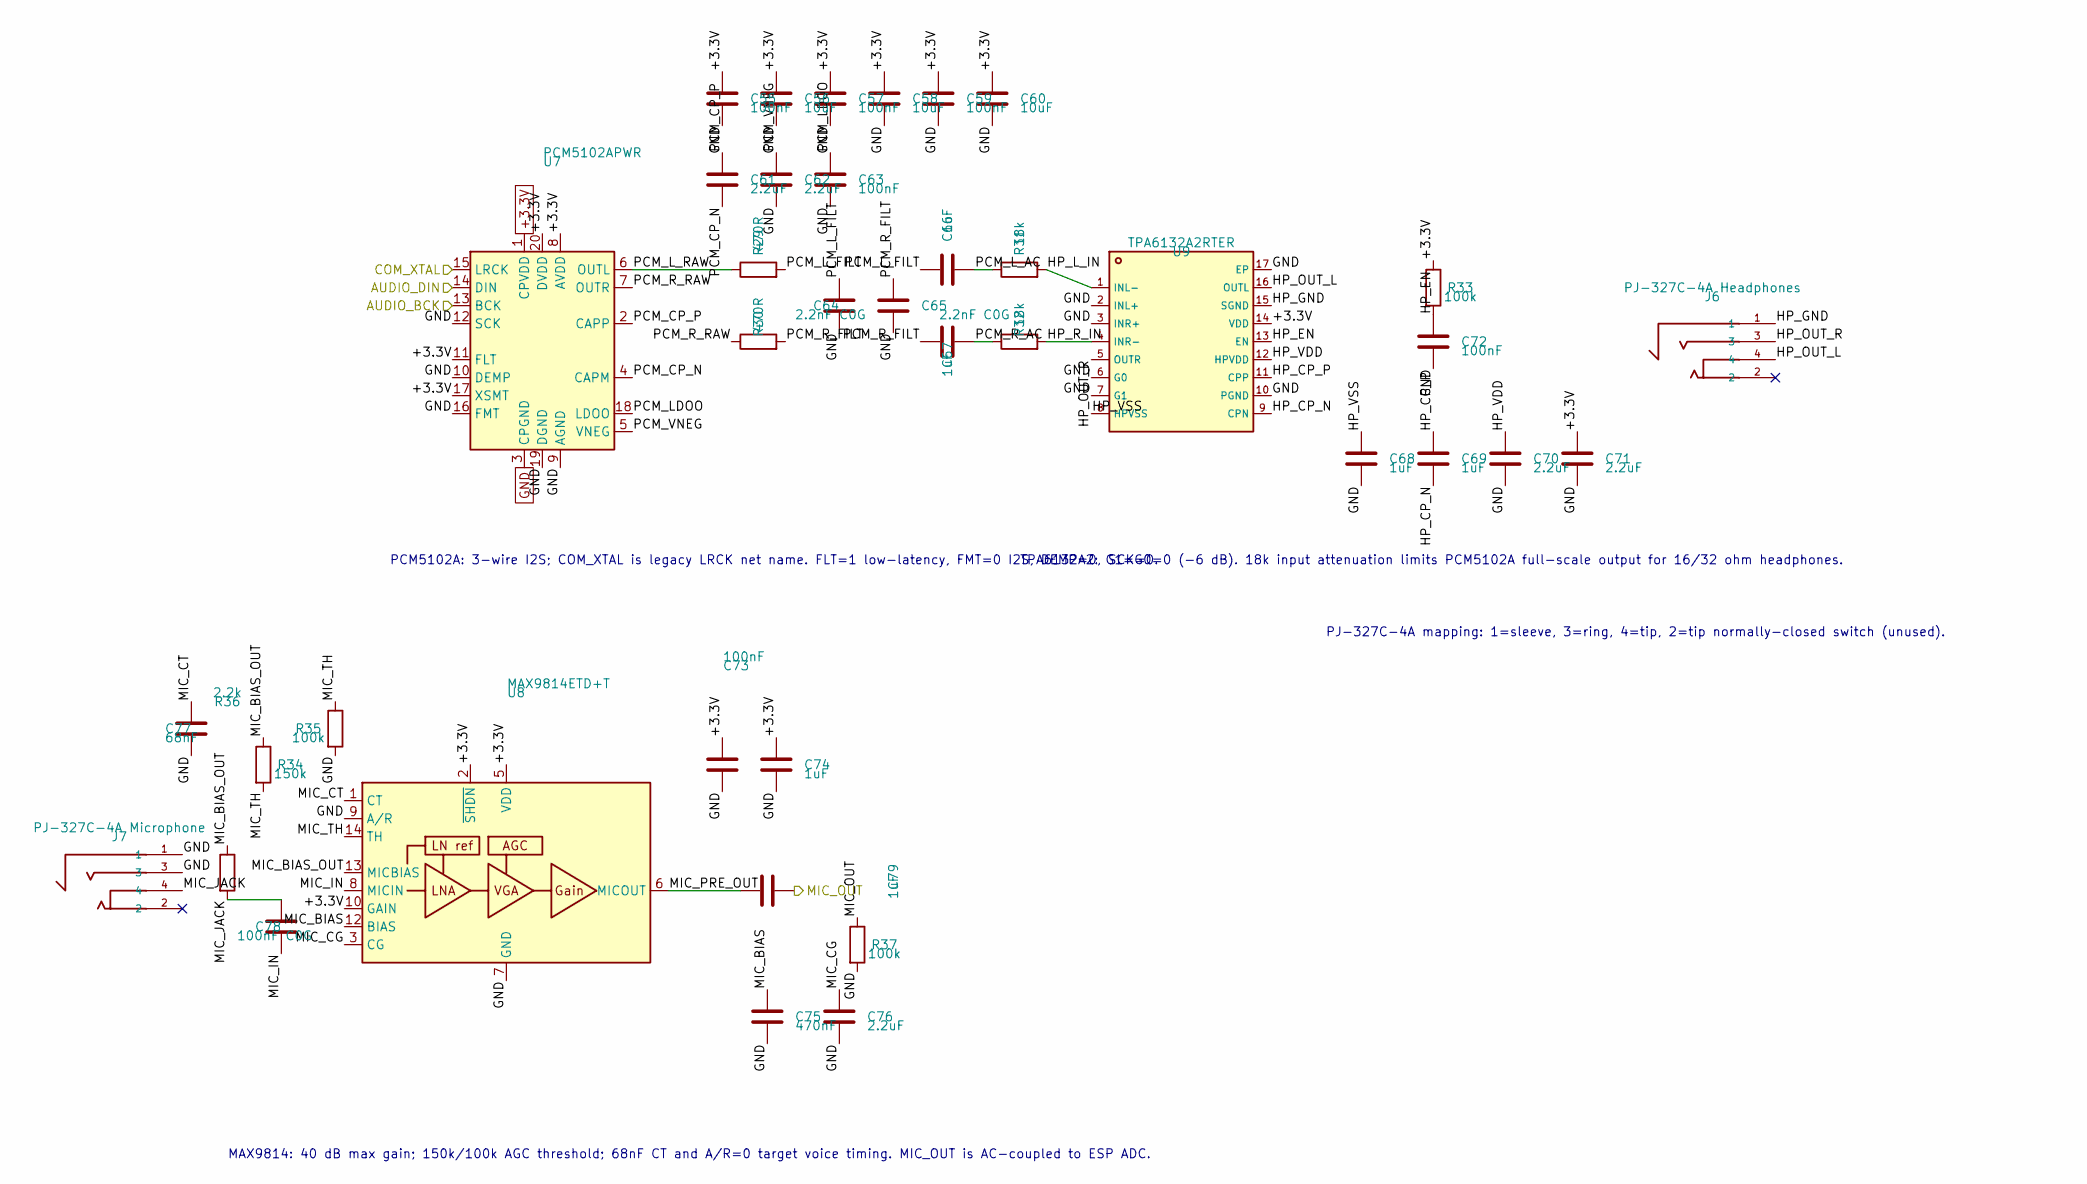
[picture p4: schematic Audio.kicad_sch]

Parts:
C55, C57, C59, C63, C72, C73: 100nF; C_0603_1608Metric; MNF PART NUMBER CC0603KRX7R7BB104; LCSC C108079
C56, C58, C60: 10uF; C_0805_2012Metric; MNF PART NUMBER TCC0805X5R106K100FT; LCSC C380331
C61, C62, C70, C71, C76: 2.2uF; C_0603_1608Metric; MNF PART NUMBER CC0603KRX7R6BB225; LCSC C513691
C64, C65: 2.2nF C0G; C_0603_1608Metric; MNF PART NUMBER CC0603JRNPO9BN222; LCSC C107043
C66, C67, C68, C69, C74, C79: 1uF; C_0603_1608Metric; MNF PART NUMBER CC0603KRX7R6BB105; LCSC C113807
C75: 470nF; C_0603_1608Metric; MNF PART NUMBER CC0603KRX7R7BB474; LCSC C1623
C77: 68nF; C_0603_1608Metric; MNF PART NUMBER CC0603KRX7R8BB683; LCSC C107071
C78: 100nF C0G; C_1206_3216Metric; MNF PART NUMBER 1206N104J500CT; LCSC C170182
J6: PJ-327C-4A Headphones; AUDIO-SMD_PJ-327C-4A; MNF PART NUMBER PJ-327C-4A; LCSC C145813
J7: PJ-327C-4A Microphone; AUDIO-SMD_PJ-327C-4A; MNF PART NUMBER PJ-327C-4A; LCSC C145813
R29, R30: 470R; R_0603_1608Metric; MNF PART NUMBER 0603WAF4700T5E; LCSC C23179
R31, R32: 18k; R_0603_1608Metric; MNF PART NUMBER 0603WAF1802T5E; LCSC C25810
R33, R35, R37: 100k; R_0603_1608Metric; MNF PART NUMBER 0603WAF1003T5E; LCSC C25803
R34: 150k; R_0603_1608Metric; MNF PART NUMBER 0603WAF1503T5E; LCSC C22807
R36: 2.2k; R_0603_1608Metric; MNF PART NUMBER 0603WAF2201T5E; LCSC C4190
U7: PCM5102APWR; TSSOP-20_L6.5-W4.4-P0.65-LS6.4-BL; MNF PART NUMBER PCM5102APWR; LCSC C107671
U8: MAX9814ETD+T; TDFN-14_L3.0-W3.0-P0.40-BL-EP; MNF PART NUMBER MAX9814ETD+T; LCSC C41714
U9: TPA6132A2RTER; WQFN-16_L3.0-W3.0-P0.50-TL-EP1.6; MNF PART NUMBER TPA6132A2RTER; LCSC C69901

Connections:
+3.3V: C55.1, C56.1, C57.1, C58.1, C59.1, C60.1, C71.1, C73.1, C74.1, R33.1, U7.1 (CPVDD), U7.8 (AVDD), U7.11 (FLT), U7.17 (XSMT), U7.20 (DVDD), U8.2 (~SHDN), U8.5 (VDD), U8.10 (GAIN), U9.14 (VDD); also elsewhere on the board
/AUDIO_BCK: U7.13 (BCK); also elsewhere on the board
/AUDIO_DIN: U7.14 (DIN); also elsewhere on the board
/Audio/HP_CP_N: C69.2, U9.9 (CPN)
/Audio/HP_CP_P: C69.1, U9.11 (CPP)
/Audio/HP_EN: C72.1, R33.2, U9.13 (EN)
/Audio/HP_GND: J6.1, U9.15 (SGND)
/Audio/HP_L_IN: R31.2, U9.1 (INL-)
/Audio/HP_OUT_L: J6.4, U9.16 (OUTL)
/Audio/HP_OUT_R: J6.3, U9.5 (OUTR)
/Audio/HP_R_IN: R32.2, U9.4 (INR-)
/Audio/HP_VDD: C70.1, U9.12 (HPVDD)
/Audio/HP_VSS: C68.1, U9.8 (HPVSS)
/Audio/MIC_BIAS: C75.1, U8.12 (BIAS)
/Audio/MIC_BIAS_OUT: R34.1, R36.1, U8.13 (MICBIAS)
/Audio/MIC_CG: C76.1, U8.3 (CG)
/Audio/MIC_CT: C77.1, U8.1 (CT)
/Audio/MIC_IN: C78.2, U8.8 (MICIN)
/Audio/MIC_JACK: C78.1, J7.4, R36.2
/Audio/MIC_PRE_OUT: C79.1, U8.6 (MICOUT)
/Audio/MIC_TH: R34.2, R35.1, U8.14 (TH)
/Audio/PCM_CP_N: C61.2, U7.4 (CAPM)
/Audio/PCM_CP_P: C61.1, U7.2 (CAPP)
/Audio/PCM_LDOO: C63.1, U7.18 (LDOO)
/Audio/PCM_L_AC: C66.2, R31.1
/Audio/PCM_L_FILT: C64.1, C66.1, R29.2
/Audio/PCM_L_RAW: R29.1, U7.6 (OUTL)
/Audio/PCM_R_AC: C67.2, R32.1
/Audio/PCM_R_FILT: C65.1, C67.1, R30.2
/Audio/PCM_R_RAW: R30.1, U7.7 (OUTR)
/Audio/PCM_VNEG: C62.1, U7.5 (VNEG)
/COM_XTAL: U7.15 (LRCK); also elsewhere on the board
/MIC_OUT: C79.2, R37.1; also elsewhere on the board
GND: C55.2, C56.2, C57.2, C58.2, C59.2, C60.2, C62.2, C63.2, C64.2, C65.2, C68.2, C70.2, C71.2, C72.2, C73.2, C74.2, C75.2, C76.2, C77.2, J7.1, J7.3, R35.2, R37.2, U7.3 (CPGND), U7.9 (AGND), U7.10 (DEMP), U7.12 (SCK), U7.16 (FMT), U7.19 (DGND), U8.4 (GND), U8.7 (GND), U8.9 (A/R), U8.11 (GND), U8.15 (GND), U9.2 (INL+), U9.3 (INR+), U9.6 (G0), U9.7 (G1), U9.10 (PGND), U9.17 (EP); also elsewhere on the board

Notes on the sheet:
PCM5102A: 3-wire I2S; COM_XTAL is legacy LRCK net name. FLT=1 low-latency, FMT=0 I2S, DEMP=0, SCK=0.
TPA6132A2: G1=G0=0 (-6 dB). 18k input attenuation limits PCM5102A full-scale output for 16/32 ohm headphones.
PJ-327C-4A mapping: 1=sleeve, 3=ring, 4=tip, 2=tip normally-closed switch (unused).
MAX9814: 40 dB max gain; 150k/100k AGC threshold; 68nF CT and A/R=0 target voice timing. MIC_OUT is AC-coupled to ESP ADC.

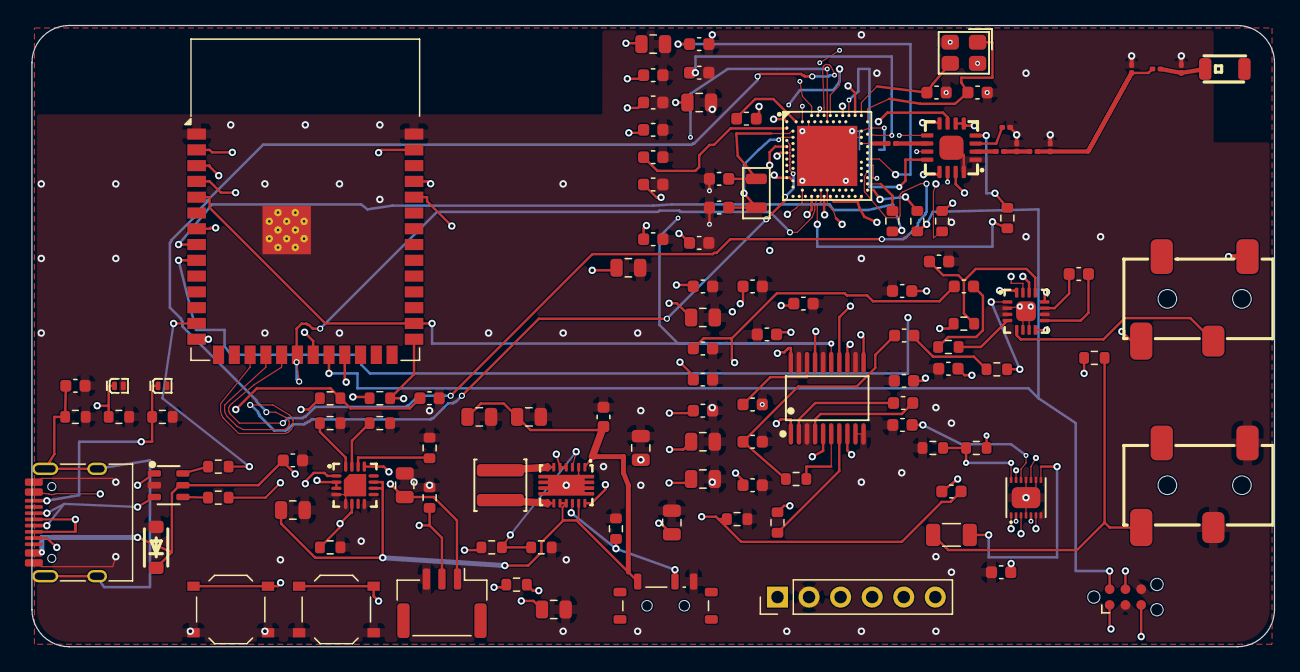
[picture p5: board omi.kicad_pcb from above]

Board: 4 copper layers, 100.0 x 50.0 mm, 117 parts (1 on the bottom side), 99 nets.

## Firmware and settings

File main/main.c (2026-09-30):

/**
 * @file main.c
 * @brief OMI - Open Motorcycle Intercom
 *
 * Boot orchestration for the ESP32-S3 firmware: transport detection,
 * subsystem wiring, the mesh toggle button, and the periodic health loop.
 */

#include <inttypes.h>
#include <stdatomic.h>

#include "freertos/FreeRTOS.h"
#include "freertos/task.h"
#include "freertos/queue.h"

#include "esp_event.h"
#include "esp_heap_caps.h"
#include "esp_log.h"
#include "esp_netif.h"
#include "esp_system.h"
#include "esp_timer.h"
#include "esp_wifi.h"
#include "sdkconfig.h"

#include "app_state.h"
#include "audio.h"
#include "button.h"
#include "button_control.h"
#include "call_policy.h"
#include "call_cues.h"
#include "call_privacy.h"
#include "cpu_profile.h"
#include "e2e_diag.h"
#include "mesh.h"
#include "mesh_intent.h"
#include "mesh_channel_pref.h"
#include "runtime_channel_control.h"
#include "media_toggle_guard.h"
#include "nvs_flash.h"
#include "omi_board_pins.h"
#include "power.h"
#include "phone_audio.h"
#include "rtt_probe.h"
#include "transport_espnow.h"
#include "transport_nrf.h"
#include "uart_bridge.h"

static const char *TAG = "omi";

/* Debug instrumentation knobs */
#define REDUCED_LOGGING_MODE 1

/* Test knob: bypass VOX gating and always transmit microphone frames.
 * 0 = normal VOX behavior (DTX silence suppression active), 1 = force continuous TX. */
#define FORCE_TX_ALWAYS_FOR_TEST 0

/* RTT log cadence while using nRF transport */
#define RTT_LOG_INTERVAL_MS 10000

_Atomic bool g_mesh_active = false;
typedef struct { button_id_t id; button_event_t event; } button_action_t;
static QueueHandle_t s_button_actions;
static atomic_uint s_button_drops = ATOMIC_VAR_INIT(0);
static atomic_bool s_channel_transition = ATOMIC_VAR_INIT(false);
static bool s_esp_channel_pending;
static bool s_esp_enable_announcement_pending;
static bool s_role_announced;
static bool s_last_coordinator;
static media_toggle_guard_t s_media_toggle_guard;
static omi_call_policy_t s_call_policy;
static omi_privacy_reconcile_t s_privacy;
static atomic_uint s_end_beeps_pending = ATOMIC_VAR_INIT(0);
static int64_t s_privacy_retry_ms;
static unsigned s_privacy_failures;
static bool s_bridge_was_ready;
static uint32_t s_bridge_status_generation;
static int64_t s_privacy_transition_ms;

/*
 * Runtime transport selection: nRF52840 (ESB via SPI bridge) or ESP-NOW (WiFi).
 * On boot, attempt SPI-bridge detection. If nRF52840 responds, use it.
 * Otherwise, fallback to ESP-NOW mesh.
 */

typedef enum {
    TRANSPORT_NONE,
    TRANSPORT_ESP_NOW,  /* ESP-NOW mesh (WiFi) */
    TRANSPORT_NRF52840, /* nRF52840 ESB via SPI bridge */
} transport_type_t;

static transport_type_t s_active_transport = TRANSPORT_NONE;

/**
 * @brief Get monotonic timestamp in milliseconds
 */
static inline int64_t get_time_ms(void)
{
    return esp_timer_get_time() / 1000;
}

/**
 * @brief Initialize NVS (required for persistent storage)
 */
static esp_err_t init_nvs(void)
{
    esp_err_t ret = nvs_flash_init();
    if (ret == ESP_ERR_NVS_NO_FREE_PAGES || ret == ESP_ERR_NVS_NEW_VERSION_FOUND) {
        ESP_LOGW(TAG, "NVS partition truncated, erasing...");
        ESP_ERROR_CHECK(nvs_flash_erase());
        ret = nvs_flash_init();
    }
    return ret;
}

static void disable_esp_wifi_for_nrf_transport(void)
{
#if CONFIG_ESP_WIFI_ENABLED
    esp_err_t ret = esp_wifi_stop();
    if (ret != ESP_OK && ret != ESP_ERR_WIFI_NOT_INIT && ret != ESP_ERR_WIFI_NOT_STARTED) {
        ESP_LOGW(TAG, "WiFi stop failed during nRF handoff: %s", esp_err_to_name(ret));
    }

    ret = esp_wifi_deinit();
    if (ret != ESP_OK && ret != ESP_ERR_WIFI_NOT_INIT) {
        ESP_LOGW(TAG, "WiFi deinit failed during nRF handoff: %s", esp_err_to_name(ret));
    }

    ret = esp_event_loop_delete_default();
    if (ret != ESP_OK && ret != ESP_ERR_INVALID_STATE) {
        ESP_LOGW(TAG, "Event loop delete failed during nRF handoff: %s", esp_err_to_name(ret));
    }

    ret = esp_netif_deinit();
    if (ret != ESP_OK && ret != ESP_ERR_INVALID_STATE) {
        ESP_LOGW(TAG, "Netif deinit failed during nRF handoff: %s", esp_err_to_name(ret));
    }

    ESP_LOGI(TAG, "ESP WiFi/ESP-NOW disabled for nRF transport");
#else
    ESP_LOGI(TAG, "ESP WiFi disabled in build config");
#endif

#if CONFIG_BT_ENABLED
    ESP_LOGI(TAG, "Bluetooth remains available for phone audio");
#else
    ESP_LOGI(TAG, "ESP Bluetooth disabled in build config");
#endif
}

static esp_err_t init_audio_with_test_flags(void)
{
    audio_config_t audio_cfg = AUDIO_CONFIG_DEFAULT();
    audio_cfg.force_tx_always = (FORCE_TX_ALWAYS_FOR_TEST != 0);
    return audio_init_with_config(&audio_cfg);
}

/**
 * @brief Callback from audio subsystem when encoded frame is ready
 */
static void audio_tx_callback(const uint8_t *data, uint16_t len, bool active,
                              int64_t timestamp_us, uint32_t mesh_epoch)
{
    if (atomic_load(&s_channel_transition) || !audio_mesh_tx_epoch_allowed(mesh_epoch)) return;
    switch (s_active_transport) {
    case TRANSPORT_ESP_NOW:
        transport_espnow_send_audio(data, len, active);
        break;

    case TRANSPORT_NRF52840:
        transport_nrf_send_audio(data, len, active, timestamp_us, mesh_epoch);
        break;

    default:
        /* No transport active */
        break;
    }
}

static void phone_call_callback(const phone_audio_call_state_t *state, void *context)
{
    (void)context;
    omi_call_decision_t decision = omi_call_policy_step(&s_call_policy, state);
    /* This is the only call-path operation that closes the local mesh gate;
     * transport commands and decoder resets belong to the main owner task. */
    audio_mesh_call_update(decision.privacy);
    if (decision.privacy && s_active_transport == TRANSPORT_ESP_NOW)
        mesh_request_local_audio_pause();
    if (decision.announce) audio_set_incoming_call(true);
    else if (!decision.current_incoming) audio_set_incoming_call(false);
    if (decision.end_beep) atomic_fetch_add(&s_end_beeps_pending, 1u);
}

static void process_call_cues(void)
{
    unsigned pending = atomic_load(&s_end_beeps_pending);
    if (pending != 0u) {
        esp_err_t ret = audio_play_call_end();
        if (omi_call_end_acknowledged(pending, ret == ESP_OK))
            atomic_fetch_sub(&s_end_beeps_pending, 1u);
    }
}

static void privacy_failed(const char *step, esp_err_t ret, int64_t now_ms)
{
    s_privacy_failures++;
    s_privacy_retry_ms = now_ms + (s_privacy_failures < 3u ? 200 : 1000);
    if (s_privacy_failures == 1u || s_privacy_failures == 3u || s_privacy_failures % 30u == 0u)
        ESP_LOGW(TAG, "Call privacy %s pending: %s", step, esp_err_to_name(ret));
}

static void reconcile_call_privacy(int64_t now_ms)
{
    uint32_t epoch = audio_mesh_call_epoch();
    bool active = audio_mesh_call_active();
    bool blocked = audio_mesh_call_blocked();
    if (epoch != s_privacy.epoch) {
        s_privacy_retry_ms = 0;
        s_privacy_failures = 0;
        s_privacy_transition_ms = now_ms;
    }
    if (s_active_transport == TRANSPORT_NRF52840) {
        uart_bridge_status_t status;
        bool ready = uart_bridge_get_status(&status) == ESP_OK &&
                     status.protocol_version == BRIDGE_PROTOCOL_VERSION;
        if (!ready) {
            if (s_bridge_was_ready) {
                s_privacy.pause_acked = false;
                s_privacy.resumed = false;
            }
            s_bridge_was_ready = false;
        } else {
            if (!s_bridge_was_ready ||
                (status.continuity_lost && status.generation != s_bridge_status_generation)) {
                if (blocked) s_privacy.pause_acked = false;
                s_privacy.resumed = false;
            }
            s_bridge_was_ready = true;
            s_bridge_status_generation = status.generation;
        }
        if (!ready) return;
    }
    omi_privacy_action_t action = omi_privacy_next(&s_privacy, epoch, active, blocked);
    if (action == OMI_PRIVACY_NONE) {
        /* A bridge restart can lose its local pause flag even after a prior
         * successful resume; restore the unpaused state on the new session. */
        if (s_active_transport == TRANSPORT_NRF52840 && !blocked && !s_privacy.resumed &&
            s_privacy.epoch != 0u && now_ms >= s_privacy_retry_ms) {
            esp_err_t ret = uart_bridge_mesh_audio_resume();
            if (ret == ESP_OK) { s_privacy.resumed = true; s_privacy_failures = 0; }
            else privacy_failed("restore resume", ret, now_ms);
        }
        return;
    }
    if (action == OMI_PRIVACY_RESUME &&
        !omi_privacy_resume_settled(now_ms, s_privacy_transition_ms)) return;
    if (now_ms < s_privacy_retry_ms) return;
    esp_err_t ret = ESP_OK;
    if (action == OMI_PRIVACY_PAUSE) {
        if (s_active_transport == TRANSPORT_NRF52840) {
            uart_bridge_discard_pending_audio();
            transport_nrf_reset_tx_cache();
            e2e_diag_reset_all_sources();
            ret = uart_bridge_mesh_audio_pause();
        } else if (s_active_transport == TRANSPORT_ESP_NOW) {
            ret = mesh_set_local_audio_enabled(false);
        }
        if (ret == ESP_OK) ret = audio_reset_mesh_rx();
        if (ret == ESP_OK && epoch == audio_mesh_call_epoch()) s_privacy.pause_acked = true;
    } else {
        if (s_active_transport == TRANSPORT_NRF52840) {
            uart_bridge_discard_pending_audio();
            transport_nrf_reset_tx_cache();
            e2e_diag_reset_all_sources();
        } else if (s_active_transport == TRANSPORT_ESP_NOW) {
            /* Keep the producer disabled while the decoder and local stores flush. */
            ret = mesh_set_local_audio_enabled(false);
        }
        if (ret == ESP_OK) ret = audio_reset_mesh_rx();
        if (ret == ESP_OK && s_active_transport == TRANSPORT_NRF52840)
            ret = uart_bridge_mesh_audio_resume();
        if (ret == ESP_OK && epoch == audio_mesh_call_epoch() && !audio_mesh_call_active()) {
            if (s_active_transport == TRANSPORT_ESP_NOW)
                ret = mesh_set_local_audio_enabled(true);
            if (ret == ESP_OK) {
                bool reopened = audio_mesh_call_resume(epoch);
                if (!reopened && s_active_transport == TRANSPORT_ESP_NOW)
                    (void)mesh_set_local_audio_enabled(false);
                if (reopened) s_privacy.resumed = true;
            }
        }
    }
    if (ret != ESP_OK) privacy_failed(action == OMI_PRIVACY_PAUSE ? "pause" : "resume", ret, now_ms);
    else { s_privacy_failures = 0; s_privacy_retry_ms = 0; }
}

static void audio_tx_idle_callback(int64_t timestamp_us)
{
    if (atomic_load(&s_channel_transition)) return;
    if (s_active_transport == TRANSPORT_NRF52840) {
        transport_nrf_skip_audio_frame(timestamp_us);
    }
}

static void audio_activity_callback(bool active)
{
    if (active) {
        power_notify_voice_start();
    } else {
        power_notify_voice_end();
    }
}

static void disable_mesh_from_button(void)
{
    ESP_LOGI(TAG, "Disabling mesh networking...");

    esp_err_t ret = ESP_OK;
    if (s_active_transport == TRANSPORT_ESP_NOW) {
        ret = mesh_stop();
    }
    /* The nRF transport is reconciled from app_main, never from this callback. */

    if (ret == ESP_OK) {
        atomic_store(&g_mesh_active, false);
        transport_nrf_cancel_enable_notification();
        transport_nrf_reset_membership_tracking();
        (void)audio_reset_mesh_rx();
        s_role_announced = false;
        (void)audio_play_notification(AUDIO_NOTIFY_MESH_DISABLED);
        ESP_LOGI(TAG, "Mesh disabled");
    } else {
        transport_nrf_set_user_enabled(true);
        transport_nrf_cancel_enable_notification();
        esp_err_t persist_ret = mesh_intent_persist(true);
        if (persist_ret != ESP_OK) {
            ESP_LOGE(TAG, "Failed to restore enabled mesh intent: %s",
                     esp_err_to_name(persist_ret));
        }
        ESP_LOGE(TAG, "Failed to stop mesh: %s", esp_err_to_name(ret));
    }
}

static void enable_mesh_from_button(void)
{
    ESP_LOGI(TAG, "Enabling mesh networking...");
    atomic_store(&g_mesh_active, false);

    esp_err_t ret = ESP_OK;
    if (s_active_transport == TRANSPORT_ESP_NOW) {
        ret = mesh_start();
    }
    /* The nRF transport is reconciled from app_main, never from this callback. */

    if (ret == ESP_OK) {
        if (s_active_transport == TRANSPORT_ESP_NOW) {
            atomic_store(&g_mesh_active, true);
            transport_nrf_cancel_enable_notification();
            (void)audio_play_notification(AUDIO_NOTIFY_MESH_ENABLED);
        }
        ESP_LOGI(TAG, "Mesh enable accepted; waiting for active state");
    } else {
        transport_nrf_set_user_enabled(false);
        esp_err_t persist_ret = mesh_intent_persist(false);
        if (persist_ret != ESP_OK) {
            ESP_LOGE(TAG, "Failed to restore disabled mesh intent: %s",
                     esp_err_to_name(persist_ret));
        }
        atomic_store(&g_mesh_active, false);
        ESP_LOGE(TAG, "Failed to start mesh: %s", esp_err_to_name(ret));
    }
}

/** Enqueue release events without blocking the button task. */
static void button_action_callback(button_id_t id, button_event_t event, void *context)
{
    (void)context;
    button_action_t action = {.id = id, .event = event};
    if (xQueueSend(s_button_actions, &action, 0) != pdTRUE) atomic_fetch_add(&s_button_drops, 1);
}

static void process_mesh_toggle(void)
{
    bool requested_enabled = !mesh_intent_enabled();
    esp_err_t ret = mesh_intent_persist(requested_enabled);
    if (ret != ESP_OK) {
        ESP_LOGE(TAG, "Failed to persist mesh intent: %s", esp_err_to_name(ret));
        return;
    }
    transport_nrf_set_user_enabled(requested_enabled);
    transport_nrf_reset_reconciliation();

    if (requested_enabled && s_esp_channel_pending) {
        s_esp_enable_announcement_pending = true;
        ESP_LOGI(TAG, "Mesh enable pending selected channel application");
        return;
    }
    if (!requested_enabled) s_esp_enable_announcement_pending = false;
    if (requested_enabled) {
        enable_mesh_from_button();
    } else {
        disable_mesh_from_button();
    }
}

static void process_pairing_request(void)
{
    esp_err_t ret = phone_audio_set_discoverable(true);
    if (ret == ESP_OK) {
        (void)audio_play_notification(AUDIO_NOTIFY_BLUETOOTH_PAIRING);
        ESP_LOGI(TAG, "Center hold opened Bluetooth pairing window for 120 seconds");
    } else {
        ESP_LOGW(TAG, "Center pairing unavailable: %s", esp_err_to_name(ret));
    }
}

static void process_media_toggle(bool request_pending, int64_t now_ms)
{
    phone_audio_state_t phone_state;
    if (phone_audio_get_state(&phone_state) != ESP_OK) {
        media_toggle_guard_reset(&s_media_toggle_guard);
        return;
    }

    bool valid = phone_state.call.phase == PHONE_AUDIO_CALL_PHASE_IDLE &&
                 phone_state.a2dp_connected && phone_state.avrcp_connected;
    now_ms = get_time_ms();
    media_toggle_decision_t decision = media_toggle_guard_step(
        &s_media_toggle_guard, request_pending, valid, phone_state.media_streaming,
        phone_state.media_transition_ms, now_ms);
    if (decision == MEDIA_TOGGLE_DROPPED) {
        ESP_LOGW(TAG, "Media toggle dropped: A2DP state transition was not observed");
    } else if (decision == MEDIA_TOGGLE_DISPATCH) {
        bool sent_streaming = phone_state.media_streaming;
        esp_err_t ret = sent_streaming ? phone_audio_pause() : phone_audio_play();
        bool arm_guard = ret != ESP_ERR_NO_MEM;
        media_toggle_guard_command_result(&s_media_toggle_guard, arm_guard,
                                          sent_streaming, get_time_ms());
        ESP_LOGI(TAG, "Center press: %s media (%s)",
                 sent_streaming ? "pause" : "play", esp_err_to_name(ret));
    }
}

static void process_short_press(int64_t now_ms)
{
    phone_audio_state_t phone_state;
    esp_err_t ret = phone_audio_get_state(&phone_state);
    if (ret != ESP_OK) {
        ESP_LOGW(TAG, "Center press state unavailable: %s", esp_err_to_name(ret));
        return;
    }

    switch (phone_state.call.phase) {
        case PHONE_AUDIO_CALL_PHASE_INCOMING:
            media_toggle_guard_reset(&s_media_toggle_guard);
            audio_set_incoming_call(false);
            ret = phone_audio_answer_call();
            ESP_LOGI(TAG, "Center press: answer call (%s)", esp_err_to_name(ret));
            return;
        case PHONE_AUDIO_CALL_PHASE_OUTGOING_DIALING:
        case PHONE_AUDIO_CALL_PHASE_OUTGOING_ALERTING:
        case PHONE_AUDIO_CALL_PHASE_ACTIVE:
        case PHONE_AUDIO_CALL_PHASE_HELD:
            media_toggle_guard_reset(&s_media_toggle_guard);
            ret = phone_audio_reject_call();
            ESP_LOGI(TAG, "Center press: end call (%s)", esp_err_to_name(ret));
            return;
        case PHONE_AUDIO_CALL_PHASE_IDLE:
            break;
    }

    if (audio_mesh_call_active()) {
        media_toggle_guard_reset(&s_media_toggle_guard);
        ret = phone_audio_reject_call();
        ESP_LOGI(TAG, "Center press: end held call (%s)", esp_err_to_name(ret));
        return;
    }

    if (phone_audio_get_call_state(&phone_state.call) != ESP_OK ||
        phone_state.call.phase != PHONE_AUDIO_CALL_PHASE_IDLE) {
        media_toggle_guard_reset(&s_media_toggle_guard);
        ESP_LOGI(TAG, "Center press: media action skipped because call is no longer idle");
        return;
    }
    process_media_toggle(true, now_ms);
}

static audio_notify_t channel_voice(uint8_t channel)
{
    return (audio_notify_t)(AUDIO_NOTIFY_CHANNEL_GREEN + channel - 1);
}

static void apply_pending_esp_channel(void)
{
    if (!s_esp_channel_pending) return;
    if (!omi_esp_channel_can_apply(mesh_get_state() == MESH_STATE_IDLE, mesh_is_quiesced())) return;
    uint8_t target = mesh_channel_pref_selected();
    esp_err_t ret = mesh_set_talk_channel(target);
    if (ret == ESP_OK) {
        if (mesh_intent_enabled()) ret = mesh_start();
    }
    if (ret != ESP_OK) {
        ESP_LOGE(TAG, "Talk channel %u pending radio application: %s", target, esp_err_to_name(ret));
        return;
    }
    s_esp_channel_pending = false;
    atomic_store(&s_channel_transition, false);
    atomic_store(&g_mesh_active, mesh_intent_enabled());
    if (s_esp_enable_announcement_pending && mesh_intent_enabled())
        (void)audio_play_notification(AUDIO_NOTIFY_MESH_ENABLED);
    s_esp_enable_announcement_pending = false;
    ESP_LOGI(TAG, "Talk channel %u active on ESP-NOW RF %u", target, mesh_channel_espnow_rf(target));
}

static void process_channel_selection(int direction)
{
    uint8_t target = mesh_channel_cycle(mesh_channel_pref_selected(), direction);
    esp_err_t ret = mesh_channel_pref_persist(target);
    if (ret != ESP_OK) {
        ESP_LOGE(TAG, "Talk channel %u not selected (NVS commit failed): %s", target,
                 esp_err_to_name(ret));
        return;
    }
    esp_err_t led = board_set_channel_indicator(target);
    if (led != ESP_OK) ESP_LOGW(TAG, "Talk channel indicator unavailable: %s", esp_err_to_name(led));
    (void)audio_play_notification(channel_voice(target));
    ESP_LOGI(TAG, "Selected talk channel %u; radio may still be pending", target);
    atomic_store(&s_channel_transition, true);
    atomic_store(&g_mesh_active, false);
    s_role_announced = false;
    if (s_active_transport == TRANSPORT_NRF52840) {
        ret = transport_nrf_set_channel(target);
        uart_bridge_discard_pending_audio();
        transport_nrf_reset_tx_cache();
    } else if (s_active_transport == TRANSPORT_ESP_NOW) {
        s_esp_channel_pending = true;
        ret = mesh_stop();
        if (ret != ESP_OK && mesh_is_quiesced())
            ESP_LOGW(TAG, "Mesh stop returned %s but quiesced; proceeding with channel change",
                     esp_err_to_name(ret));
    }
    esp_err_t flush = audio_reset_mesh_rx();
    if (flush != ESP_OK) {
        ESP_LOGE(TAG, "Mesh RX flush failed; channel %u held pending: %s", target, esp_err_to_name(flush));
        /* Do not allow a new session to admit old audio until a successful flush. */
        return;
    }
    if (s_active_transport == TRANSPORT_ESP_NOW &&
        !omi_esp_channel_can_apply(mesh_get_state() == MESH_STATE_IDLE, mesh_is_quiesced())) {
        ESP_LOGE(TAG, "Talk channel %u pending mesh quiescence (stop: %s)", target,
                 esp_err_to_name(ret));
        return;
    }
    if (ret != ESP_OK && s_active_transport != TRANSPORT_ESP_NOW) {
        ESP_LOGE(TAG, "Talk channel %u pending transport stop: %s", target, esp_err_to_name(ret));
        return;
    }
    if (s_active_transport == TRANSPORT_ESP_NOW) apply_pending_esp_channel();
    else atomic_store(&s_channel_transition, false); /* nRF gates through confirmed ACK. */
}
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
void app_main(void)
{
    int64_t boot_time = get_time_ms();

    if (initialize_application(boot_time) != ESP_OK) {
        goto error_halt;
    }

    run_runtime_health_loop(boot_time);

    /* Cleanup (unreachable in normal operation) */
    mesh_stop();
    mesh_deinit();
    phone_audio_deinit();
    audio_stop();
    audio_deinit();
    return;

error_halt:
    ESP_LOGE(TAG, "System halted due to initialization error");
    while (1) {
        vTaskDelay(pdMS_TO_TICKS(1000));
    }
}

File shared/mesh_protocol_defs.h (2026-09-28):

/**
 * @file mesh_protocol_defs.h
 * @brief Single source of truth for the OMI on-air mesh protocol.
 *
 * These definitions are shared verbatim by both transports:
 *   - ESP-NOW build  (components/mesh/include/mesh.h)
 *   - nRF52840/ESB   (nrf_mesh/include/mesh_protocol.h)
 *
 * Only definitions that MUST be byte-identical on the wire live here. Anything
 * that legitimately differs per transport (e.g. the coordinator/peer address
 * width: 6-byte WiFi MAC for ESP-NOW vs 5-byte ESB pipe address) stays in the
 * per-platform header. Do not add platform-specific fields to this file.
 *
 * Plain C only: no esp_err.h / Zephyr includes, and no extern "C" (the
 * including header provides linkage). Include it from both platform headers.
 */

#ifndef OMI_MESH_PROTOCOL_DEFS_H
#define OMI_MESH_PROTOCOL_DEFS_H

#include <stddef.h>
#include <stdint.h>
#include "mesh_channel.h"

/* ============================================================================
 * Protocol constants (wire-visible)
 * ============================================================================ */

#define MESH_MAX_NODES                  8
#define MESH_FRAME_MS                   20   /* TDMA frame duration */
#define MESH_SLOT_MS                    2    /* TDMA slot duration */
#define MESH_GUARD_US                   500  /* Guard time between slots */
#define MESH_SYNC_INTERVAL_FRAMES       10   /* SYNC broadcast cadence */
#define MESH_NODE_TIMEOUT_MS            3000 /* Drop peer after this silence */
#define MESH_KEEPALIVE_INTERVAL_MS      500  /* KEEPALIVE cadence */
#define MESH_PROTOCOL_VERSION           0x05
#define MESH_CONTROL_MAX_PACKET_SIZE    209U
#define MESH_MAX_OPUS_BYTES             64
#define MESH_LC3_FRAME_BYTES            48
#define MESH_E2E_SEQUENCE_BYTES         2
#define MESH_MAX_AUDIO_PAYLOAD          (MESH_MAX_OPUS_BYTES + MESH_E2E_SEQUENCE_BYTES)
#define MESH_AUDIO_V2_CODEC_OPUS        0x01
#define MESH_AUDIO_V2_CODEC_LC3         0x02
#define MESH_AUDIO_CODEC_OPUS            0x01
#define MESH_AUDIO_CODEC_LC3             0x02
#define MESH_CAP_OPUS                    0x01
#define MESH_CAP_LC3                     0x02
#define MESH_AUDIO_V2_FRAME_MS          20
#define MESH_AUDIO_V2_FIXED_HEADER_SIZE 8
#define MESH_AUDIO_V2_MAX_FRAME_BYTES   64
#define MESH_AUDIO_V2_MAX_FRAME_DATA    (3 * MESH_AUDIO_V2_MAX_FRAME_BYTES)
#define MESH_AUDIO_V2_MAX_BUNDLE_SIZE                                                              \
    (MESH_AUDIO_V2_FIXED_HEADER_SIZE + MESH_AUDIO_V2_MAX_FRAME_DATA)
#define MESH_AUDIO_V2_MAX_PACKET_SIZE (9 + MESH_AUDIO_V2_MAX_BUNDLE_SIZE)
#define MESH_MAX_ACTIVE_SPEAKERS      2 /* Concurrent relay-granted speakers */
#define MESH_AUDIO_TTL_DEFAULT        2 /* Default relay TTL */

/* Header control flags */
#define MESH_FLAG_RELAY_REQUEST   0x01
#define MESH_FLAG_RELAYED         0x02
#define MESH_FLAG_SPEAKER_GRANTED 0x04

/* Audio payload flags */
#define MESH_AUDIO_FLAG_ACTIVE               0x01
#define MESH_AUDIO_FLAG_RELAYED              0x02
#define MESH_AUDIO_V2_FLAG_CURRENT_ACTIVE    0x01
#define MESH_AUDIO_V2_FLAG_PREVIOUS1_PRESENT 0x02
#define MESH_AUDIO_V2_FLAG_PREVIOUS1_ACTIVE  0x04
#define MESH_AUDIO_V2_FLAG_PREVIOUS2_PRESENT 0x08
#define MESH_AUDIO_V2_FLAG_PREVIOUS2_ACTIVE  0x10
#define MESH_AUDIO_V2_FLAG_RELAYED           0x20
#define MESH_AUDIO_V2_FLAG_MASK              0x3F

/* ============================================================================
 * Enums
 * ============================================================================ */

typedef enum {
    MESH_ROLE_NONE = 0,    /* Not connected to mesh */
    MESH_ROLE_COORDINATOR, /* Time master / coordinator */
    MESH_ROLE_PARTICIPANT, /* Time slave / participant */
} mesh_role_t;

typedef enum {
    MESH_STATE_IDLE = 0, /* Not started */
    MESH_STATE_SCANNING, /* Listening for existing mesh */
    MESH_STATE_JOINING,  /* Sending JOIN requests */
    MESH_STATE_ACTIVE,   /* Connected and active */
} mesh_state_t;
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

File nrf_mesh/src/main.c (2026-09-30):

/**
 * @file main.c
 * @brief OMI Mesh Firmware Entry Point
 *
 * Initializes ESB radio, UART bridge, TDMA timing, and starts mesh protocol
 */

#include <zephyr/kernel.h>
#include <zephyr/logging/log.h>
#include <zephyr/usb/usb_device.h>

#include "esb_radio.h"
#include "mesh_protocol.h"
#include "tdma.h"
#include "uart_bridge.h"
#include "ws_sync.h"

LOG_MODULE_REGISTER(main, LOG_LEVEL_INF);

/* SPI poll cadence for ESP32 bridge */
#define SPI_POLL_MS 2

/* Dedicated SPI bridge thread to minimize main-loop jitter */
#define SPI_THREAD_STACK_SIZE 2048
#define SPI_THREAD_PRIORITY   -1

K_THREAD_STACK_DEFINE(s_spi_thread_stack, SPI_THREAD_STACK_SIZE);
static struct k_thread s_spi_thread;
static volatile uint32_t s_spi_loop_count = 0;

static void spi_bridge_thread(void *arg1, void *arg2, void *arg3)
{
    ARG_UNUSED(arg1);
    ARG_UNUSED(arg2);
    ARG_UNUSED(arg3);

    int64_t next_wake_ms = k_uptime_get();

    while (1) {
        uart_bridge_process();
        s_spi_loop_count++;

        next_wake_ms += SPI_POLL_MS;
        int64_t now_ms = k_uptime_get();
        int32_t sleep_ms = (int32_t)(next_wake_ms - now_ms);

        if (sleep_ms > 0) {
            k_sleep(K_MSEC(sleep_ms));
        } else {
            if (sleep_ms < -20) {
                next_wake_ms = now_ms;
            }
            k_yield();
        }
    }
}

int main(void)
{
    int ret;

    /* Initialize UART bridge FIRST - must be ready before ESP32 sends probe.
     * ESP32 sends PING within ~200ms of boot, so this must happen immediately. */
    int bridge_ret = uart_bridge_init();

    /* Enable USB subsystem for logging (works even without a USB host) */
    ret = usb_enable(NULL);
    if (ret != 0 && ret != -EALREADY) {
        return ret;
    }

    /* Short delay for USB CDC enumeration before first output */
    k_sleep(K_MSEC(1000));

    printk("\n\n*** OMI Mesh Firmware booted ***\n\n");
    printk("Firmware version: %s\n", OMI_FIRMWARE_VERSION);
    printk("Git SHA: %s\n", OMI_GIT_SHA);

    if (bridge_ret != 0 && bridge_ret != -EALREADY) {
        printk("[DIAG] UART bridge init FAILED: %d\n", bridge_ret);
        return bridge_ret;
    }

    if (!uart_bridge_is_initialized()) {
        printk("[DIAG] UART bridge init FAILED\n");
    } else {
        printk("[DIAG] UART bridge init OK\n");
    }

    /* Initialize ESB radio */
    printk("[DIAG] Initializing ESB radio...\n");
    ret = esb_radio_init(mesh_channel_esb_rf(MESH_CHANNEL_DEFAULT));
    if (ret) {
        printk("[DIAG] ESB radio init FAILED: %d\n", ret);
        return ret;
    }
    printk("[DIAG] ESB radio OK\n");

    /* Initialize TDMA timing */
    printk("[DIAG] Initializing TDMA...\n");
    ret = tdma_init();
    if (ret) {
        printk("[DIAG] TDMA init FAILED: %d\n", ret);
        return ret;
    }
    printk("[DIAG] TDMA OK\n");

    /* Initialize WS sync capture diagnostics */
    printk("[DIAG] Initializing WS sync capture...\n");
    ret = ws_sync_init();
    if (ret) {
        printk("[DIAG] WS sync init FAILED: %d (continuing without sync)\n", ret);
    } else {
        printk("[DIAG] WS sync OK\n");
        ws_sync_start();
    }

    /* Initialize mesh protocol */
    printk("[DIAG] Initializing mesh protocol...\n");
    ret = mesh_protocol_init();
    if (ret) {
        printk("[DIAG] Mesh protocol init FAILED: %d\n", ret);
        return ret;
    }
    printk("[DIAG] Mesh protocol OK\n");

    /* NOTE: Don't start mesh automatically - wait for ESP32 command.
     * This allows both boards to be ready before mesh discovery starts,
     * ensuring proper coordinator election. */
    printk("[DIAG] Mesh initialized, waiting for ESP32 enable command\n");

    /* Start dedicated SPI polling thread and let main loop stay lightweight */
    k_thread_create(&s_spi_thread, s_spi_thread_stack, K_THREAD_STACK_SIZEOF(s_spi_thread_stack),
                    spi_bridge_thread, NULL, NULL, NULL, SPI_THREAD_PRIORITY, 0, K_NO_WAIT);
    printk("[DIAG] Entering main loop (SPI thread active)\n");

    uint32_t loop_count = 0;
    while (1) {
        loop_count++;
        if (loop_count % 100 == 0) {
            printk("."); /* Quick heartbeat every 10 seconds */
        }
        if (loop_count % 300 == 0) {
            printk("\n[DIAG] heartbeat: main=%u spi=%u\n", loop_count, s_spi_loop_count);
        }

        /* Sleep to let other tasks run */
        k_sleep(K_MSEC(100));
    }

    return 0;
}

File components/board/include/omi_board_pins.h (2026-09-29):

/**
 * @file omi_board_pins.h
 * @brief ESP32-S31 Function CoreBoard-1 GPIO map.
 */

#ifndef OMI_BOARD_PINS_H
#define OMI_BOARD_PINS_H

#include <stdint.h>
#include "sdkconfig.h"
#include "esp_err.h"

#if !defined(CONFIG_IDF_TARGET_ESP32S31)
#error "omi_board_pins.h requires the ESP32-S31 target"
#endif

/* Onboard audio codec: codec is the I2S clock/data peer. */
#define OMI_BOARD_GPIO_AUDIO_I2C_SCL  50
#define OMI_BOARD_GPIO_AUDIO_I2C_SDA  51
#define OMI_BOARD_GPIO_AUDIO_I2S_MCLK 52
#define OMI_BOARD_GPIO_AUDIO_I2S_BCLK 53
#define OMI_BOARD_GPIO_AUDIO_I2S_DIN  54 /* codec microphone data -> ESP32 */
#define OMI_BOARD_GPIO_AUDIO_I2S_WS   55
#define OMI_BOARD_GPIO_AUDIO_I2S_DOUT 56 /* ESP32 -> codec playback data */
#define OMI_BOARD_GPIO_AUDIO_AMP_EN   57

/* Onboard controls. */
#define OMI_BOARD_GPIO_BOOT_BUTTON 61
#define OMI_BOARD_GPIO_RGB         60
/* External normally-open buttons to J2 GND (pin 8); J2 pins 12, 7, 10. */
#define OMI_BOARD_GPIO_BUTTON_MINUS  1
#define OMI_BOARD_GPIO_BUTTON_CENTER 2
#define OMI_BOARD_GPIO_BUTTON_PLUS   3

/* nRF bridge on J2. */
#define OMI_BOARD_GPIO_NRF_ACK          42 /* nRF -> ESP32 ACK */
#define OMI_BOARD_GPIO_NRF_SPI_MISO     43 /* ESP32 slave output -> nRF master input */
#define OMI_BOARD_GPIO_NRF_SPI_MOSI     44 /* nRF master output -> ESP32 slave input */
#define OMI_BOARD_GPIO_NRF_SPI_SCLK     45 /* nRF master clock -> ESP32 slave */
#define OMI_BOARD_GPIO_NRF_SPI_CS       46 /* nRF master chip select -> ESP32 slave */
#define OMI_BOARD_GPIO_NRF_I2S_WS_SYNC  47 /* ESP32 I2S WS output -> nRF sync input */

/* Reserved for UART0; these pins are intentionally not assigned to consumers. */
#define OMI_BOARD_GPIO_UART0_RX 58
#define OMI_BOARD_GPIO_UART0_TX 59

/** Connect I2S0 master WS to the nRF bridge sync input GPIO. */
esp_err_t omi_board_nrf_i2s_ws_sync_connect(void);

/** Disconnect the nRF bridge sync input and reset it to a neutral input. */
esp_err_t omi_board_nrf_i2s_ws_sync_disconnect(void);

/** Set the onboard RGB indicator to the logical mesh channel color (1 green, 2 red, 3 blue). */
esp_err_t board_set_channel_indicator(uint8_t channel);

#endif /* OMI_BOARD_PINS_H */

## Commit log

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2026-01-22 feat(phase0): Initialization
    Repository structure
    ESP-IDF + CMake
    Opus build integration
    Logging framework with timestamps
    Hardware selection
    Firmware skeleton
    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
    [partitions.csv]
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2026-01-23 fix: board2 serial hangs after reset
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2026-01-26 fix(phase4): High pitched mic playback
    [audio.c]
2026-01-26 fix(phase2): Use MAX9814 and decrease attenuation
    [audio.c]
2026-02-08 feat: Enable or disable mesh intercom
    Allows for saving battery when the mesh is not needed (solo rider).
    Will make more sense once bluetooth is in place.
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2026-03-21 fix: bottleneck in nRF-ESP SPI
    [audio.c, main.c, uart_bridge.c]
2026-03-21 feat: noise and echo supression
    [audio.c]
2026-03-21 refactor: modularize jitter and audio
    [audio.c, main.c]
2026-03-21 fix: SPI 100ms poll stalls
    [main.c]
2026-03-21 fix: sync filtering and decimation
2026-03-21 feat: OMI initial schematics
    [omi.kicad_pcb, omi.kicad_sch]
2026-03-22 fix: Missing protocol status, CRC and others
    [main.c, uart_bridge.c]
2026-03-22 fix: Dropped packages and underruns
    [uart_bridge.c]
2026-03-22 fix: Improve audio jitter and cuts
    [audio.c]
2026-03-23 fix: Opus PLC to fix robotic voice
    [audio.c]
2026-03-24 feat: Update schematics for common xtal
    [omi.kicad_sch]
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2026-03-24 fix: LEAVE or LOST audio beep, switch to channel 40
    [main.c, uart_bridge.c]
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2026-03-24 revert: feat: Get rid of SPI drops
    This reverts commit 4f6dd60d8cc122c7aaff47bbf9811395b35bdb97.
    [audio.c, main.c, uart_bridge.c]
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2026-03-24 fix: Reduce latency by 20ms by smaller queues
    [audio.c, uart_bridge.c]
2026-03-25 fix: Increase transmission_power to 8dBm
    --- Quick Summary ---
    /dev/ttyACM1 (nRF): spi_gap=0.0% | rf_gap=0.52% | rf_delivery=99.78%
    /dev/ttyACM3 (nRF): spi_gap=0.39% | rf_gap=0.15% | rf_delivery=99.91%
    /dev/ttyACM4 (ESP): glitches=0 (0.0/min) | e2e_delivery=99.8% |
    e2e_gap=0.15%
    Latency: total avg=59ms max=82ms | TX avg=18.9ms max=38.0ms | RX
    avg=38.4ms max=80.4ms | enc avg=8.3ms | dec avg=0.9ms
    /dev/ttyACM5 (ESP): glitches=0 (0.0/min) | e2e_delivery=99.62% |
    e2e_gap=0.8%
    Latency: total avg=59ms max=92ms | TX avg=18.8ms max=41.9ms | RX
    avg=35.4ms max=75.2ms | enc avg=8.2ms | dec avg=0.9ms
    [main.c]
2026-03-26 feat: multi-hop and ESB 250kbps
    /dev/ttyACM2 (nRF): spi_gap=0.0% | rf_gap=0.17% | rf_delivery=99.63%
    /dev/ttyACM3 (nRF): spi_gap=0.0% | rf_gap=0.22% | rf_delivery=99.96%
    /dev/ttyACM4 (ESP): glitches=0 (0.0/min) | e2e_delivery=99.62% |
    e2e_gap=0.35%
    Latency: total avg=59ms max=79ms | TX avg=18.7ms max=28.5ms | RX
    avg=32.3ms max=78.3ms | enc avg=8.3ms | dec avg=0.9ms
    /dev/ttyACM5 (ESP): glitches=0 (0.0/min) | e2e_delivery=99.77% |
    e2e_gap=0.38%
    Latency: total avg=59ms max=93ms | TX avg=18.9ms max=39.3ms | RX
    avg=42.1ms max=88.7ms | enc avg=8.2ms | dec avg=0.9ms
    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
    [audio.c, main.c, uart_bridge.c]
2026-03-26 fix: minor bugs from multi-hop
    /dev/ttyACM2 (nRF): spi_gap=0.0% | rf_gap=0.13% | rf_delivery=99.93%
    /dev/ttyACM3 (nRF): spi_gap=0.0% | rf_gap=0.25% | rf_delivery=99.75%
    /dev/ttyACM4 (ESP): glitches=0 (0.0/min) | e2e_delivery=99.67% |
    e2e_gap=0.3%
    Latency: total avg=59ms max=79ms | TX avg=18.8ms max=28.0ms | RX
    avg=36.1ms max=78.9ms | enc avg=8.4ms | dec avg=0.9ms
    /dev/ttyACM5 (ESP): glitches=0 (0.0/min) | e2e_delivery=100.05% |
    e2e_gap=0.2%
    Latency: total avg=59ms max=83ms | TX avg=18.9ms max=39.3ms | RX
    avg=42.6ms max=86.8ms | enc avg=8.3ms | dec avg=0.9ms
    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
    [main.c]
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2026-06-17 feat: per-peer timeout for ESB mesh
    Drop peers that go silent past MESH_NODE_TIMEOUT_MS (3s) via a 1 Hz
    check in status_work_handler, mirroring the ESP-NOW path. Liveness is
    refreshed by keepalive/status/audio/join, all independent of voice
    activity, so silence-suppressed nodes stay alive. Skips self and the
    coordinator (whose loss is handled by the SYNC_TIMEOUT re-election path).
2026-06-17 feat: suppress radio TX during silence via Opus DTX
    Enable Opus DTX and transmit only comfort-noise (SID) updates during
    VOX silence, dropping the 1-2 byte DTX frames so the radio goes quiet.
    Plumb the per-frame active flag end-to-end so the receiver treats DTX
    gaps as intentional silence (no false underrun/glitch counts) rather
    than packet loss; ESP-NOW defaults to active so its behavior is
    unchanged. Disable FORCE_TX_ALWAYS_FOR_TEST so gating engages.
    [audio.c, main.c]
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2026-06-18 docs: document nRF mesh-state concurrency invariant
    The nRF speaker-grant / peer state has no locks, but it is not racy: all
    access is confined to the system workqueue (rx/status/slot work run
    serially), and the ISR paths only k_work_submit. Document this invariant
    so future changes don't introduce a second context without adding
    synchronization (unlike the ESP-NOW build, which has a real timer/task
    split guarded by s_speaker_mux).
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2026-07-29 feat: publish final OMI v1 hardware
    [Audio.kicad_sch, Radio.kicad_sch, USB_Power.kicad_sch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]
2026-07-31 fix: stabilize real-time mesh audio transport
    [audio.c, main.c, mesh_protocol_defs.h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]
2026-07-31 fix: exclude RTT probes from audio metrics
2026-07-31 fix: skip unnecessary mesh relays
2026-07-31 fix: recover mesh after nRF reboot
    [main.c]
2026-07-31 fix: resolve mesh lifecycle QA findings
    [audio.c, main.c, uart_bridge.c]
2026-07-31 fix: recover delayed TDMA frame scheduling
2026-08-01 fix: stabilize nRF TDMA phase discipline
    [main.c]
2026-08-01 fix: harden bridge status and membership
    [audio.c, main.c, uart_bridge.c]
2026-08-02 fix: conceal lost audio frames at playout
    Received audio had frequent short gaps while telemetry reported no
    glitches. The end-to-end sequence number was parsed for statistics and
    then dropped before the jitter buffer, so the decoder never learned a
    frame was missing and simply decoded the next packet.
    Carry the sequence into playout and rebuild each missing frame with
    Opus PLC, holding the newer packet back so one output frame is produced
    per sender frame. Runs longer than eight frames resynchronise instead.
    Grace-empty and catch-up frames now consume their sequence slot, so a
    burst is not concealed twice. The grace advance is skipped during DTX
    silence, where the sender consumes no seque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
    [audio.c, main.c]
2026-08-02 fix: widen mesh playout buffer
    [audio.c]
2026-08-02 refactor: send single-predecessor audio bundles
    prev2 recovered under 0.3% of frames while tripling worst-case
    payload airtime. Keep prev1, which recovers nearly all isolated
    losses; Opus PLC covers rare consecutive losses. Worst-case
    bundle shrinks from 200 to 141 bytes.
2026-08-02 feat: raise mesh radio bitrate to 2 Mbps
    Halves slot airtime (worst bundle ~0.7 ms of a 2 ms slot) to make
    room for larger meshes. Airtime estimator updated for the 2 Mbps
    preamble and per-byte time. Desk-range raw loss is unchanged;
    receive pipeline latency drops with the shorter transmissions.
2026-08-02 feat: grant speakers by talk-spurt order
    Replace lowest-node-id-wins grant selection with first-speaker
    precedence: granted speakers keep their slot while active, and
    free slots go to the earliest talk-spurt start. Selection lives
    in shared mesh_core as a pure function with unit tests.
2026-08-02 feat: mix up to three remote talkers
    Raise AUDIO_MAX_RX_SOURCES to 3 and add top-N selection: a new
    active talker displaces the source that has been VOX-silent for
    at least 400 ms. Recently active talkers keep their slot, and
    keepalive-only streams never evict anyone.
2026-08-02 refactor: extract RX source selection policy
    Move the top-N slot decision (match, free slot, evict after
    400 ms silence, reject) into a pure host-testable unit with a
    focused test suite. audio.c keeps all side effects and stats.
2026-08-02 refactor: extract audio TX predecessor cache
    Move the prev1 attach policy (consecutive sequence, active,
    eligible while mesh enabled) from main.c into a shared pure
    module with tests covering wraparound and reset paths.
    [main.c]
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2026-08-18 fix: measure real TX slot starvation
2026-08-18 fix: drain audio ingress at slot start
2026-08-18 docs: mark slot starvation phase-feedback fix
2026-08-18 chore: correct audio contracts and drop dead jitter buffer
    [audio.c]
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2026-09-21 fix: synchronize KiCad design and repair 3D models
    [Radio.kicad_sch, omi.kicad_pcb]
2026-09-21 fix(nrf_mesh): request HFXO for the ESB radio
    The nRF52840 radio needs the external 32 MHz crystal, but the ESB
    library never requests it. Only the USB driver did, while VBUS was
    present. Without USB the radio ran from the internal RC oscillator,
    was off-frequency and could neither hear nor reach other nodes even
    though SPI and mesh state looked healthy.
    esb_radio_init() now requests HFCLK through the Zephyr clock control
    on/off manager and waits for it; esb_radio_deinit() releases it.
    UF2 bootloaders can hand over with HFXO already running. nrfx then
    triggers HFCLKSTART on a running crystal, no HFCLKSTARTED event
    follows and the manager stays in "turning on". A PRE_KERNEL_1 hook
    stops a l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
2026-09-24 feat: stabilize S31 LC3 audio and add CPU profiling
    Run LC3 through a dedicated owner task and fix mesh buffering, playout recovery, and notification synthesis. Reduce Bluetooth resampling costs and skip unused echo-reference conversion. Add pipeline telemetry, optional CPU profiling, and regression tests.
    [audio.c, capture.py, esp_lc3_bench.c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]
2026-09-24 feat: carry LC3 audio over the nRF mesh bridge
    Version the mesh and bridge protocols and validate LC3 capabilities before transport selection. Reset the ES8311 during startup to recover audio after MCU resets, and add live output diagnostics.
    [main.c, mesh_protocol_defs.h, transport_nrf.c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]
2026-09-25 feat: migrate nRF firmware to NCS 3.4.1
    Update nrfx and USB configuration, GPPI routing, and CI artifacts. Switch ESB explicitly between transmit and receive roles with serialized transitions and bounded recovery.
2026-09-25 feat: suppress LC3 encoding and transmission during VOX silence
    Keep capture and Bluetooth routing active while skipping silent mesh audio. Bound quiet-slot sequence advancement and clear redundancy across pauses, with silence and resume regression coverage.
    [audio.c, e2e_diag.c, main.c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]
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2026-09-25 docs: remove power measurements
    Currently we are at 45mA. The power budget is 60mA to have reasonable
    battery life with 900mAh battery.
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2026-11-04 nrf: lift Rust Embassy nRF firmware and crates from migration/embassy
    Bring rust/nrf-embassy, rust/nrf-embassy-firmware, rust/openhelmet-wire,
    rust/openhelmet-mesh and rust/vendor/embassy-nrf-esb over unchanged from
    migration/embassy (2550ca8), including per-crate rust-toolchain/rustfmt
    config and lockfiles. Firmware feature defaults (incl. legacy-rtc-timing)
    are kept as at that commit.
    openhelmet-mesh integration tests that #[path]-include or compile the
    migration-only components/rust_embassy sources, migration C mesh files or
    openhelmet-s31-policy are pruned together with their C fixtures; the
    standalone contract tests stay. The openhelmet-wire mesh layout fixture
    passes against this bran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
2026-11-04 nrf: retire Zephyr nrf_mesh app and its C-only tests
    The nRF52840 now runs the Rust Embassy firmware in rust/. Remove the NCS
    nrf_mesh/ application, the host tests that only compiled nrf_mesh headers
    (ws_sync_math, esb_rssi, tdma_remote_rate), and shared/mesh_membership.[ch]
    whose only users were nrf_mesh and its own test (no ESP component or main/
    source compiles or includes it).
    mesh_adaptive_test drops its membership-handover asserts and keeps covering
    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
2026-11-04 ci/release: Rust nRF CI jobs and paired C-S31/Rust-nRF release build
    Add .github/workflows/rust-nrf.yml with the wire, mesh, ESB, nRF runtime and
    nRF firmware jobs from migration/embassy's rust-migration.yml (stable
    1.95.0, thumbv7em-none-eabihf, ELF->UF2 via tools/migration/nrf_proof.py and
    the release UF2 validator, plus the firmware feature matrix). The
    nrf-embassy-proof, S31 Rust policy/archive and force-TX jobs are not
    carried over.
    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
2026-11-04 fix(bridge): do not expire a status committed after the reader's clock sample
    uart_bridge_get_status and the TX dequeue sample esp_timer_get_time() before taking the status lock. A status committed in that window has received_at_us > now_us, which bridge_status_is_fresh_locked treated as not fresh: the bridge was declared disconnected, channel_confirmed cleared, and the next reconcile tick sent mesh STOP then START. Both boards then replayed the role and peer-join cues and the nRF purged its audio state (local_epoch++). Seen as bridge_status expire increments with max_age_ms far below the 5 s timeout.
    Treat a newer-than-now status as fresh; the timer is monotonic. Host test compiles the rea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
2026-11-04 fix(audio): load the mesh gate word before the RX cutoff
    audio_put_rx_frame loaded g_audio_mesh_rx_cutoff_ms and then let
    audio_mesh_call_rx_allowed load the gate word. A resume (publish cutoff,
    then reopen the word) landing between the two loads paired the stale
    pre-resume cutoff with the reopened gate and could admit a frame received
    while privacy-paused. audio_mesh_call_rx_allowed now takes a cutoff loader
    and calls it only after the gate word's acquire load, as in migration/embassy
    635576d.
    audio_mesh_call_test checks that a blocked gate never loads the cutoff and
    that a frame seeing the reopened word gets the resume's cutoff.
2026-11-04 fix(bridge): wait one tick for the TX mutex and keep logs off the audio path
    Port of the bridge TX part of migration/embassy c4c3c87:
    - send_audio_packet took tx_mutex with a 0-tick try, so brief contention
    with the SPI task dropped audio frames; it now waits one tick and counts
    full-queue and mutex failures separately (tx_q_full/tx_q_mutex).
    - The enqueue path no longer logs: send_audio_packet called the pipe-stats
    ESP_LOGI and uart_bridge_get_status (reached via uart_bridge_is_mesh_ready)
    logged telemetry and status expiry. Both now print only from
    uart_bridge_log_audio_pipe_stats, called by the main nRF 10 s loop.
    bridge_tx_enqueue_test compiles the real send_audio_packet body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
2026-11-04 fix(privacy): restore nRF audio resume after an S31 reboot at epoch zero
    reconcile_call_privacy skipped the restore RESUME while the gate epoch was
    zero. After an S31 reboot the epoch restarts at zero but the nRF can still
    be paused from before the reboot, leaving one-way silence. Drop the epoch
    check, as migration/embassy c4c3c87 did; a successful restore stays latched
    until the next bridge session. The Rust nRF treats a redundant Resume as
    idempotent.
    The condition moves into omi_privacy_restore_resume_due (call_privacy.h) so
    call_policy_test covers the epoch-zero case.
2026-11-04 fix(audio): RX source lock wait guarantees at least 1 ms
    pdMS_TO_TICKS(1) is one tick at 1 kHz, and a one-tick FreeRTOS wait expires
    at the next tick edge, i.e. after anywhere from 0 to 1 ms. audio_put_rx_frame
    then dropped frames on brief rx_sources_mutex contention (rx_lock_drop).
    Wait pdMS_TO_TICKS(1) + 1 ticks, as migration/embassy c4c3c87 did.
2026-11-04 fix(audio): avoid TX pipeline latency divide by zero on count wrap
    audio_record_tx_pipeline_latency_us divided the latency sum by a u32 frame
    count that wraps to zero after 2^32 frames. Skip the average update on that
    frame, matching the checked division in migration/embassy.
2026-11-04 fix(power): bound state names and recheck the state under the mutex
    power_set_state indexed s_state_names with an unchecked state, and it and
    power_notify_voice_start/end compared s_state outside s_state_mutex before
    transitioning, so a voice edge could act on a state another task had just
    changed (e.g. jump STANDBY -> ACTIVE_VOICE). Reject out-of-range states,
    and do the comparison and the conditional voice transitions under the
    mutex. migration/embassy closed the same race in its Rust power owner
    (d25e0c7).
    power_state_test compiles the real power.c on a host SDK shim, and fails
    on the previous code.
2026-11-04 ci: run the new bridge, power and mesh-call gate C tests under ASan/UBSan
2026-11-04 refactor: delete the dead RTT probe and legacy bridge audio send
    Both nRF firmwares reject BRIDGE_PKT_AUDIO (type 1) frames and the Rust
    nRF only emits AUDIO_V2, so the RTT probe never completed a round trip,
    and in the LC3 build it was not even ticked. Remove main/rtt_probe.*,
    shared/rtt_probe_defs.h, uart_bridge_send_audio, the transport_nrf hook,
    the always-zero [RTT] logs and the probe_rx pipe counter. A legacy
    type-1 frame from the nRF still counts as spi_invalid.
2026-11-04 refactor: delete the liblc3 lc3_bench component
    lc3_bench only built with an out-of-tree LC3_SOURCE_DIR checkout and
    was compiled out of the LC3 wire build. The production codec
    (esp_lc3_bench/esp_lc3_codec.c) and cpu_profile stay.
2026-11-04 refactor: delete the dead ESP-SR AEC, reblock and far-reference path
    AUDIO_ENABLE_ESP_SR_AEC was 0, so audio_aec_init never created a
    handle, audio_aec_process always returned false and capture always ran
    the noise-only voice cleanup against an all-zero far reference. Remove
    audio_aec.*, the AEC-only reblock layer and its test, the far-reference
    converter, PSRAM FIFO, shadows and lock, the always-false aec_* stats
    and the esp-sr dependency (dependencies.lock is not tracked). Capture
    still runs voice_cleanup in mesh mode, its timing still lands in the
    capture "aec" slot and the play_far_reference profile span is kept
    (now empty), so log and profile formats are unchanged apart from the
    dropped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
2026-11-04 refactor: delete the dead S31 diagnostic build variants
    S31_LC3_SKIP_RX, S31_LC3_SPLIT_CORES, S31_MESH_COEX_PREFER_WIFI and
    S31_MESH_PAIR_UNICAST were experiment-only and are forced OFF by the
    documented and release builds. Remove the options, their CMake guards,
    compile definitions and code paths (silent LC3 bypass, core-0 playout
    pin, Wi-Fi coexistence preference, two-node unicast), the mesh esp_coex
    PRIV_REQUIRES, and drop them from the release OFF_OPTIONS.
    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
2026-11-04 feat(audio): beep once when the phone has both A2DP and HFP up
    Add a single 120 ms 880 Hz connect beep (AUDIO_CUE_CONNECT) to the
    volume-limit cue mixer, at the same level and with the same 5 ms
    fade in/out as the limit and call-end beeps.
    main/phone_link_cue.h holds the edge: it fires once when the second
    profile connects, stays silent through a single-profile drop and
    reconnect (e.g. an A2DP re-config), and re-arms only after both
    profiles are down. The main loop polls phone state and requests the
    beep from its own task, never from a Bluedroid callback. A busy cue is
    retried; the beep is skipped while a call rings or is live, and the
    playout task cancels it if an incoming-call prompt beco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
2026-11-04 fix(audio): count just-works pairings in the open window as new bonds
    With IO cap NONE, Bluedroid auto-accepts SSP just-works pairing without a
    CFM/PIN request, so the accepted-request check never matched and "Phone
    paired" was not announced. A successful AUTH_CMPL while the pairing window
    is discoverable now counts too; bonded reconnects produce no AUTH_CMPL.
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2026-11-04 ci: build the LC3 release configuration and guard against Opus
    The plain esp-idf job build is now the release LC3 configuration. Verify
    the three S31_LC3_* options resolved ON in the CMake cache, that the LC3
    codec and its single-owner worker are linked and that no Opus symbol is.
    Add a pytest guard that rejects opus_encode, opus_decode, esp-opus,
    S31_LC3_WIRE and S31_LC3_SELFTEST under components/, main/ and tools/,
    and checks the shared mesh wire codec IDs stay defined.
2026-11-04 fix(sdkconfig): keep SPI/audio task stacks out of RTC fast RAM
    Re-apply A8: set CONFIG_ESP_SYSTEM_ALLOW_RTC_FAST_MEM_AS_HEAP=n. As heap,
    RTC fast RAM handed the SPI/audio tasks slow stacks, which caused S31 bridge
    RX loss while BT A2DP streamed.
    Bench 2026-11-03:
    - Without A8 (=y, phase-3 HEAD): mesh audio received on helmet A stuttered
    badly while A played BT A2DP music. B sent ~464 frames, A received 265
    with ~200 spi_gap (~40% loss at the S31 bridge RX); decode and playout
    were clean.
    - With A8 (=n) on phase 3: music plus mesh is audibly clean (spi_gap ~12%,
    mostly recovered by redundancy). The ESP-NOW fallback boots (WiFi init OK,
    mesh forms, audio clear both ways); internal f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
2026-11-04 fix(radio): turn Bluetooth off before the ESP-NOW mesh starts
    Mesh on with ESP-NOW started the mesh first and switched Bluetooth off only
    after mesh_start succeeded, so a connected phone still held the radio and
    its internal RAM while the mesh came up.
    The toggle now runs as a small non-blocking step in the main loop: request
    -> Bluetooth off (phone disconnected, non-connectable) -> mesh_start once
    neither A2DP nor HFP is connected, or after OMI_MESH_ON_LINK_DOWN_TIMEOUT_MS
    (2 s). "Mesh On", then "Bluetooth off", play only after the start. Mesh
    off and pairing cancel a pending start; a channel change hands it to the
    channel path, which announces once the channel applies. nRF is unchanged:
    t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
2026-11-04 feat(audio): beep an octave lower when the phone disconnects
    Add a phone-disconnected beep: one 120 ms 440 Hz tone (AUDIO_CUE_DISCONNECT),
    the connect beep's falling octave, at the same level and with the same 5 ms
    fade in/out.
    main/phone_link_cue.h now returns which beep is owed. The disconnect beep
    plays once when a connection that earned the connect beep (both A2DP and
    HFP up) goes fully down. A single-profile drop and reconnect plays nothing,
    a reconnect before the beep is accepted drops it, and a disconnect we cause
    (mesh on turning Bluetooth off) is silent because "Bluetooth off" already
    says so. Like the connect beep it is requested from the main loop, skipped
    while a call rings or i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
2026-11-04 feat(button): preview what releasing a hold would do
    The button engine now emits HOLD_LONG / HOLD_EXTRA_LONG once per press while
    a key is still held past the long-press (center 2 s, sides 1 s) and pairing
    (center 6 s) thresholds; release classification is unchanged. The main loop
    plays the prompt the release would play (Mesh On/Off, Phone Pairing, the
    channel a side hold selects) and the release skips that one prompt; follow-ups
    (Bluetooth off/on, Mesh Off before pairing) still play.
2026-11-04 docs: update for the Rust nRF firmware, LC3-only S31 build and new prompts
    Replace the NCS/Zephyr nRF build and wiring links with the Rust
    Embassy firmware, drop the removed S31 build options, Opus loopback
    and ESP-SR AEC text, document hold prompts, phone connect/disconnect
    beeps, "Phone paired" and the ESP-NOW mesh/Bluetooth exclusivity,
    and refresh third-party notices (drop ESP-SR; add ESP Audio Codec,
    embassy-nrf-esb and nrf-pac).
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
